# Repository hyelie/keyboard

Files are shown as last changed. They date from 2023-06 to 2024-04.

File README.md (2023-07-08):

# keyboard
repository for both-side-B reversed-tenkey hotswap split keyboard

## directory description
```
├─firmware
│  ├─hyelie - QMK firmware folder
│  └─kbfirmware - kbfirmware layout folder (for reference)
├─PCB
│  ├─gerber - my gerber file folder
│  └─lib - Kicad library folder
├─housing - 3D CAD folder for housing
├─specification - specifications
└─제작기 - manufacturing guide
```

## manufacturing guide

[키보드 제작기 1편. 왼쪽 PCB 설계](./%EC%A0%9C%EC%9E%91%EA%B8%B0/1.%20%EC%99%BC%EC%AA%BD%20pcb/README.md)

[키보드 제작기 2편. 양쪽 PCB 완성 및 주문](./%EC%A0%9C%EC%9E%91%EA%B8%B0/2.%20%EC%96%91%EC%AA%BD%20PCB%20%EC%99%84%EC%84%B1%20%EB%B0%8F%20%EC%A3%BC%EB%AC%B8/README.md)

[키보드 제작기 3편. 납땜 & 펌웨어 올리기](./제작기/3.%20납땜%20&%20펌웨어/README.md)

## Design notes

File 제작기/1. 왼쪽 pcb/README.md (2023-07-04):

최근들어 컴퓨터를 오래 하고 있으면 목이 자꾸 앞으로 빠지는 것 같아 스플릿 키보드를 하나 장만해야겠다고 생각했습니다. 

오쏘니 스태거니 하는 다양한 배열에 새로 적응하기 싫어 기존 배열로 찾아봤는데, 마음에 드는 배열이 없었습니다.

제일 마음에 안 드는 건 **오른쪽에 b키가 없다**는 거에요. 그래서 하나 만들기로 했습니다.

이 글은 스플릿 키보드를 제로베이스부터 만들면서 작성하는 글입니다. 저는 전공자도 아니고 회로 볼 줄도 모릅니다.
저는 맨땅에 머리 박으면서 했지만 이 글을 보는 **누군가에게 도움이 되기를** 바랍니다.
또 저도 뉴비인만큼 **고수분들께서 제 글을 보고 개선사항이나 잘못된 점을 지적**해주시면 좋겠네요.

## 목표
키보드를 만드는 방법은 크게 핸드와이어링/PCB 이렇게 2가지로 나뉘는데, 핸드와이어링의 경우 스위치나 하우징이 마음에 들지 않는 경우 처음부터 다시 만들어야 합니다.

스위치가 고장나는 일도 있을 것 같은데.. 이때마다 와이어링을 한다? 좀 아닌 것 같네요.

따라서 **핫스왑 소켓 + PCB**로 만드는 방법을 채용합니다.

 - 스플릿 키보드.
 - 양쪽에 모두 b키가 있어야 함.
 - 핫스왑 소켓. (스위치를 쉽게 교체할 수 있기 위함)
 - 텐키는 왼쪽 키보드의 왼쪽. (마우스 공간을 위함)
 - 사무실에서 사용할 수 있을 정도의 무소음, 또는 저소음
 - 오래 사용해도 손목이 아프지 않음

## 레이아웃
http://www.keyboard-layout-editor.com/
에서 키보드 레이아웃을 직접 만들어 볼 수 있습니다. 아래는 제가 목표로 하는 레이아웃입니다.

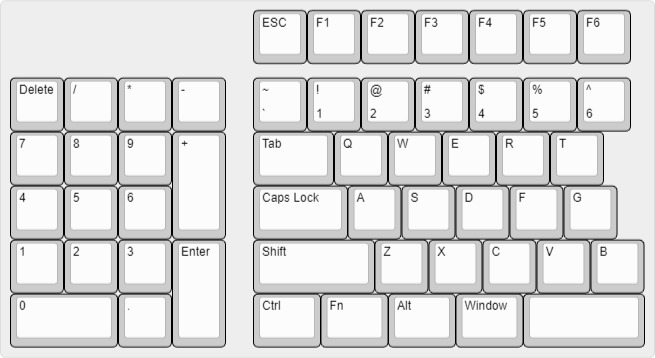
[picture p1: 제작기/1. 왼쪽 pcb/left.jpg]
left layout

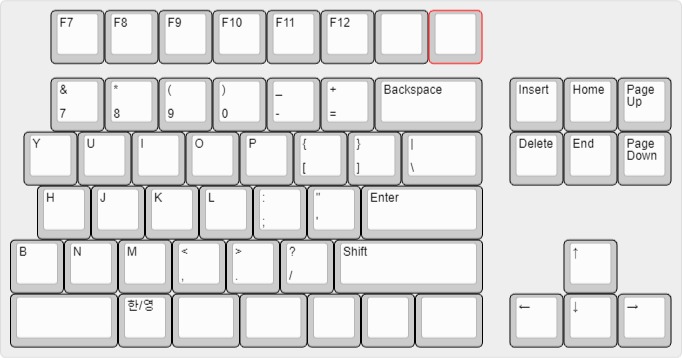
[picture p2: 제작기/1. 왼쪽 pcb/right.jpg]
right layout


기존 풀배열과 똑같습니다. F1~F12키는 자주 쓰진 않는데 없으면 서운하더군요.
텐키도 같은 맥락으로 숫자를 다라라락 입력하는 일이 많은데 텐키가 있으면 훨씬 편하니까요.
쓰잘데기없는 Number Lock이나 Print Sceen, Scroll Lock, Pause Break같은 키들을 다 지웠습니다.

참, 레이아웃을 만들 때 구입하고자 하는 **키캡을 먼저 알아보시는 것을 추천**합니다. 저의 경우는 무지성으로 레이아웃을 먼저 짰는데 오른쪽 스페이스바를 하나 더 주는 키캡이 거의 없더군요. 싼거 2개를 사던가, 여분을 매우 많이 주는 키캡을 사던가 2가지 방법 중에 하나를 택해야 할 것 같습니다. 여러분들은 키캡을 먼저 알아보시는 걸 추천드립니다...
* [키크론 체리프로파일 이중사출 PBT] 이 제품이 여분을 매우 많이 주더군요.

## 칩
칩은 국룰 칩인 ATmega32U4를 사용하려 했습니다. 그런데 칩 하나만 다는 게 아니라 파워, 축전지, 등등 신경 쓸 게 너무 많더군요.

그래서 **아두이노 프로 마이크로**를 사용하기로 했습니다. 이외에도 라즈베리 파이 피코나 Teensy 등 다양한 선택지가 있습니다.

회로에 자신있으신 분들은 직접 붙여도 될 것 같습니다. 공간활용이 훨씬 좋아지는 것 같아요.

## 좌우 연결 방법
크게 배선을 직접 잇는 방법, 케이블을 사용하는 방법 2가지로 나뉘는데, 배선을 직접 이으면 길이가 한정되어버리기 때문에 **케이블을 사용하는 방법**을 택하겠습니다.

케이블도 종류가 많은데, 많은 분들께서 TRRS 케이블을 사용해서 저도 TRRS를 택하려 했습니다...만

제가 만든 레이아웃은 풀배열인 만큼 개수가 많습니다. 좌우 모두 row가 6개, col이 11개입니다.

https://github.com/qmk/qmk_firmware/blob/master/docs/feature_split_keyboard.md

위 링크에 TRRS 케이블을 연결하는 방법이 있습니다. I2C 방식을 채용하면 되는데.. 이 방식은 핀을 2개나 먹을뿐더러 핀 사이에 뭔가 하나 더 납땜해 주어야 하네요.

여기서 문제가 하나 생깁니다. 아두이노 프로 마이크로에서 일반적으로 사용할 수 있는 핀의 개수는 18개입니다. 여기서 row 6개, col 11개를 하면 17개... 남는 핀이 없습니다.

추가로 뭔가 더 달기도 귀찮고, 아두이노 프로를 디솔해서 추가로 핀을 만들기도 두렵네요. 저는 키보드-키보드 연결 이외에 다른 연결은 하지 않을 것이니 **Serial Wiring 방식으로 TRS 연결**을 하겠습니다.

* VCC는 파워, GND는 접지, SCL은 정보가 왔다갔다하는 핀이라고 생각하시면 될 것 같습니다.

* TRS와 TRRS의 차이점은 구글링해보는 것을 추천합니다. TRS 소켓인 PJ-320이 kicad 심볼과 풋프린트를 찾기 쉽지 않아 TRRS 소켓인 PJ-320A를 사용했기 때문에, PJ-320A의 다리 4개가 어떤 역할을 하는지 정도는 알고 있으면 좋을 것 같습니다.

## 회로도
어떻게 만들지 대충 구상이 끝났습니다. 회로도를 작성할 차례입니다.

회로도는 크게 3단계로 나뉩니다.

0. 라이브러리 가져오기 + 각 심볼에 풋프린트 매핑하기
    * 제가 사용한 라이브러리는 아래에 링크로 두겠습니다.
1. 키 매트릭스 그리기
2. 키 매트릭스의 row/column과 아두이노 프로 마이크로 연결하기
3. 아두이노 프로 마이크로와 TRS 소켓 연결하기

추가로, 모두 배선을 해 버리면 굉장히 난잡해져 버리기 떄문에 [전역 라벨]이라는 기능을 활용하면 좋습니다. 같은 이름인 라벨을 같은 전선으로 이어져 있다고 취급해 줍니다.

이렇게 제가 삽질한 회로도입니다.

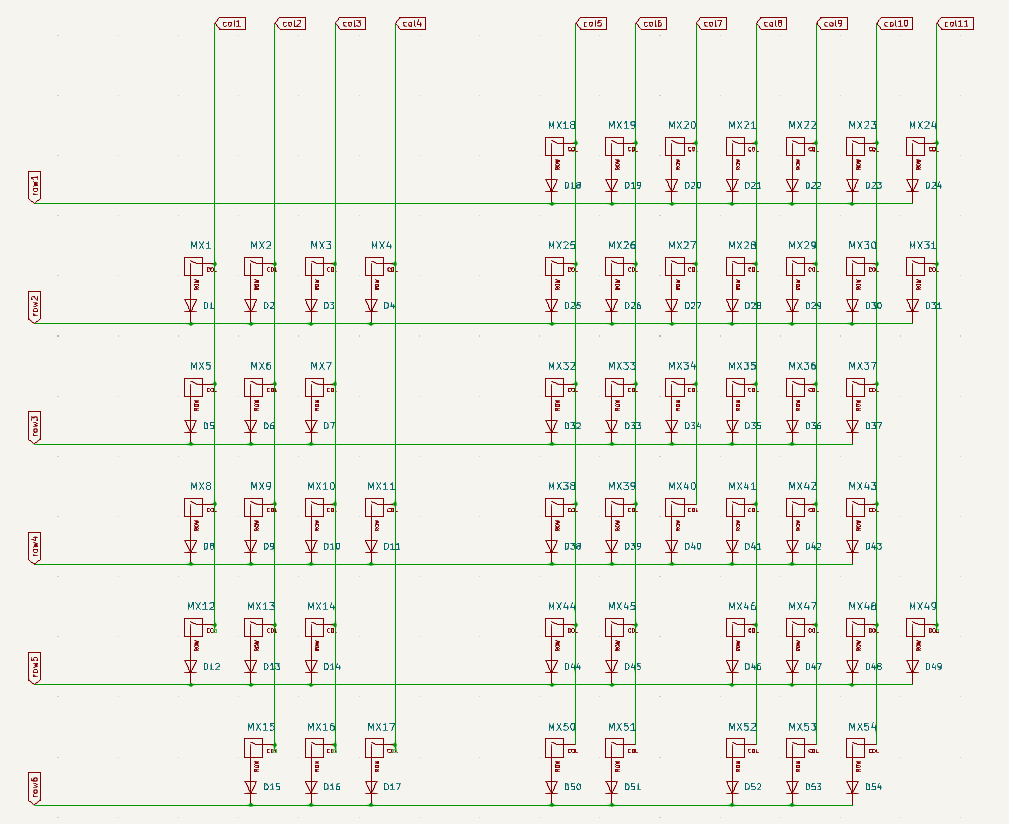
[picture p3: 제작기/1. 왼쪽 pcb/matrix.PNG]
circuit1

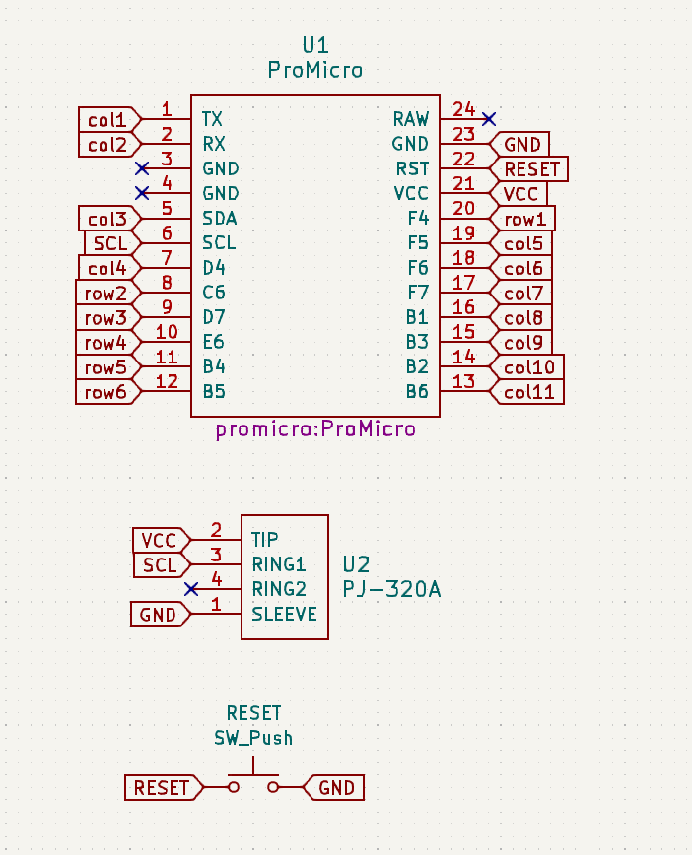
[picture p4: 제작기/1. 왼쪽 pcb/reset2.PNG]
circuit2


## PCB
회로도를 다 그렸다면, [도구 - 회로도로부터 PCB 업데이트]를 누르면 회로도에 있는 모든 심볼들에 대한 풋프린트를 로딩합니다. 만약 오류가 생겼다면... 해결하고, 풋프린트 로드를 어떻게든 해 봅시다.

PCB는 크게 2단계로 나뉩니다.

1. 로드했다면 생각했던 **레이아웃처럼 풋프린트를 배치**합니다.
2. 옅은 선으로 이어진 선(이 선들은 회로도에서 연결한 선이며, 가이드라인이라 보시면 됩니다.)를 연결합니다.

배선이 생각보다 많이 까다로웠습니다. 특히 한쪽 면으로만 배선하니까 너무 선들이 몰리는 경향이 있는 것 같아요. **양 면 모두 사용하는 것을 추천**드립니다.

추가로 [via]라는 것을 활용하면 좋습니다. 해 보시면 알겠지만 같은 면에 있는 배선은 교차할 수 없는데 **via를 사용해 선을 뒷면으로** 넘길 수 있습니다. 좀 더 공간을 활용할 수 있겟죠?

이렇게 제가 삽질한 PCB입니다.

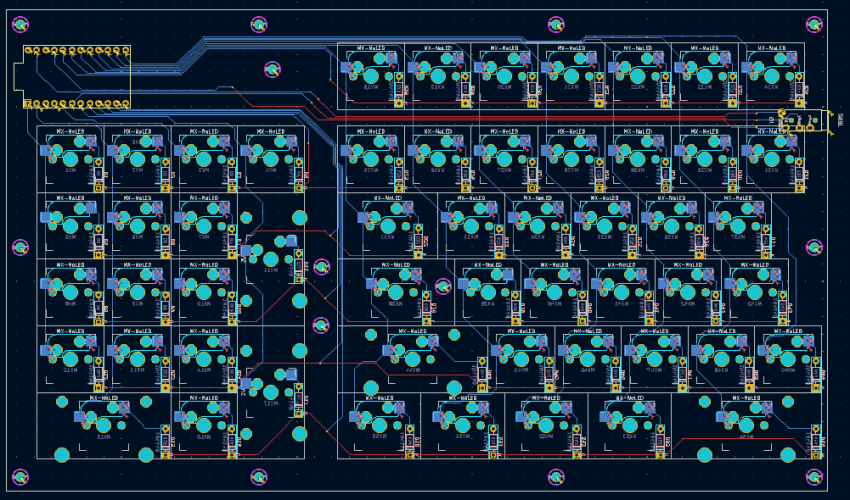
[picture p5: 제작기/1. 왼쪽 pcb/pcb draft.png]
pcb draft


* 이 때 PCB의 어느 위치에 나사를 체결할 건지도 중요하기 때문에 구멍 위치를 비워두셔야 합니다.

(추가) 리셋 버튼을 추가했습니다. 한 쪽은 아두이노 프로 마이크로의 RST와, 다른 한 쪽은 TRS의 GND와 이어줬습니다. (GND는 모두 한 선으로 이어져 있습니다.)

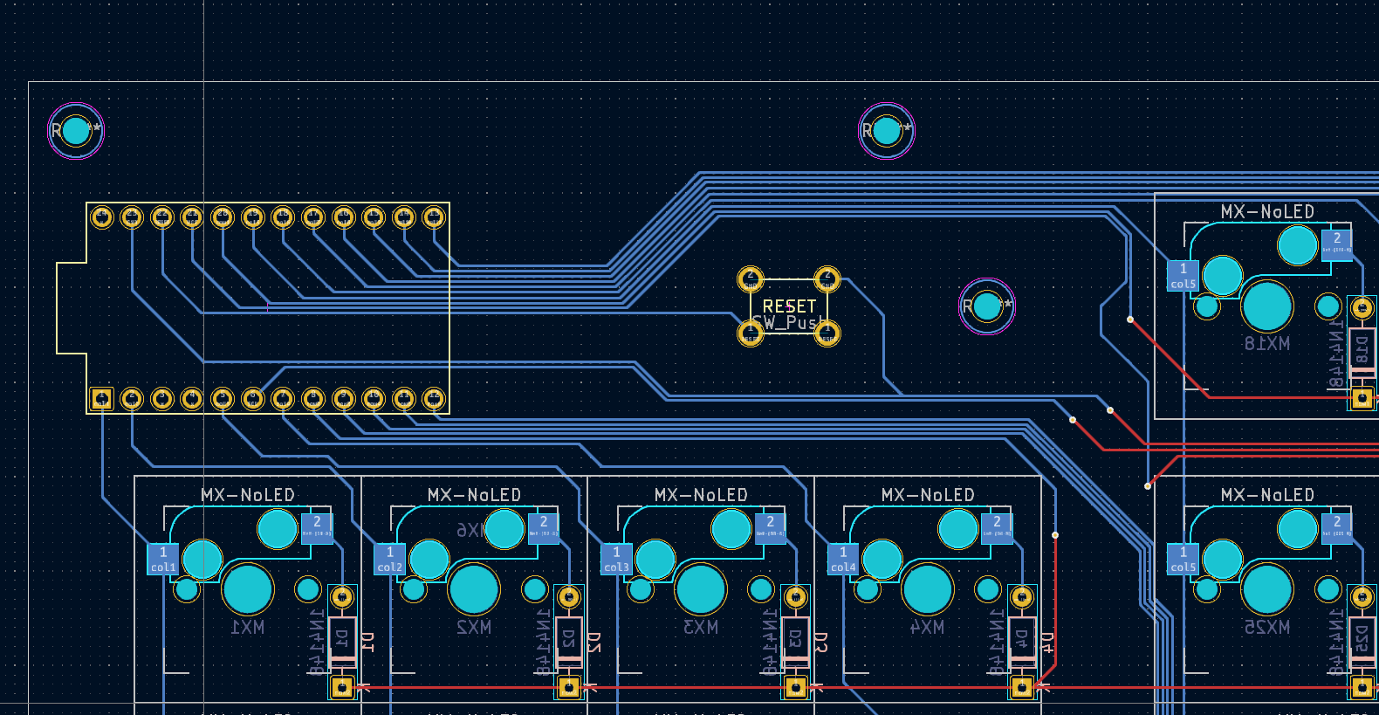
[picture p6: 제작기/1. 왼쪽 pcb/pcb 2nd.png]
pcb 2nd


## 다음...
풋프린트 검사를 돌렸을 때 별 이상이 없다면... 다음 단계로 넘어가도 될 것입니다.

다음에는 하우징과 견적내기(즐거운 쇼핑)을 하겠습니다.

## 마무리
고수분들 많은 훈수 부탁드립니다. 혹시나 풋프린트나 회로 파일 필요하시면 해당 레포지토리 안에서 찾을 수 있습니다.

## 참고
https://github.com/keebio/Keebio-Parts.pretty
 - TRRS 소켓인 PJ-320A를 가져다 썼습니다.

https://github.com/ai03-2725/MX_Alps_Hybrid
 - 키보드 스위치 심볼과 풋프린트를 가져다 썼습니다. vertical + hotswap 모두 있는 라이브러리입니다.
   
https://github.com/Biacco42/ProMicroKiCad
 - 아두이노 프로 마이크로 심볼과 풋프린트를 가져다 썼습니다.
 
https://github.com/qmk/qmk_firmware/blob/master/docs/feature_split_keyboard.md
 - TRS 연결 방법에 대해 나와있습니다.
   
https://www.clien.net/service/board/lecture/16615720
 - 키 매트릭스 만드는 방법을 참고했습니다. 설명이 잘 되어 있어요.
   
https://blog.naver.com/mine44
 - 질문 답해주셔서 감사합니다.

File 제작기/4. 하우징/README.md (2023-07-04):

녹색 선 : lock 걸린 것
검정 선 : lock 걸린 것에 dependency가 존재하는 것. 구속이 걸렸을 때 생긴다.
파란 선 : 아무것도 없이 자유롭게 움직일 수 있는 선

자주 쓰는 기능
모깎기 : 직각 선 2개를 연결하면 그 2개로 모깎기가 걸린다.
스케치 치수 : 특정 위치부터 얼마 떨어진 곳에 위치시킴. 구속이 걸린다. 단축키 D
돌출 : 해당 거리만큼 돌출시킴
offset : offset을 줄 수 있다.

parameter 관리 창 띄우는 방법 : 프로젝트 최상단 우클릭 - 타임라인 캡처 사용
수정 - 매개변수 관리

# 규격
상판 : 14 x 14 정사각형으로부터 offset 3mm, round 2mm로 깎으면 됨
스레드 인서트 규격 : M3 * Length * 외경

나사 규격
https://ko.aliexpress.com/item/1005002426046826.html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
머리 길이
M2 : 3.8mm
M2.5 : 4.5mm
M3 : 5.5mm

USB-C 규격
가로 9cm, 세로 2.56cm 정도?

스위치 규격
보강판 - 상판 끝까지 7-8mm
보강판 높이 1.5mm
보강판 - PCB 3.5mm
PCB 높이 1.6mm
PCB - 하판 3mm

아두이노 프로 마이크로 규격을 정확하게 모르니까.. 일단 집에 가서 width, height 재고 나서 그다음에 설계해야 할 듯? 안들어 갈 수도 있을 것 같음.

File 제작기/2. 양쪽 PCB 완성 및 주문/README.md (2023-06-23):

핫스왑 양쪽B 리버스텐키 스플릿키보드 제작기 2편입니다.

## 변경사항
### 목표 추가
제작하다보니 1편의 목표에서 몇 가지를 추가했습니다. 추가한 내용은 `사무실에서 사용할 수 있을 정도의 무소음, 또는 저소음`, 그리고 `오래 사용해도 손목이 아프지 않음`입니다.

### 레이아웃 변경
지난 제작기를 만든 이후, 왼쪽에 있는 텐키의 경우 숫자패드는 그대로 유지하되 `0`, `.`, `Enter`, `+` 등의 키들을 대칭이동하는 편이 좀 더 좋다`는 의견을 받았습니다. 실제로 가상 넘패드를 왼손으로 타이핑하려 하니 **엔터를 소지로, 자주 치는 0을 엄지로** 치는 게 훨씬 편했습니다. /, *, -까지는 굳이 대칭할 필요를 느끼지 못했고요.

또, 오른쪽 한영키의 우측에 있는 필요없는 키들이 아무리 봐도 이쁘지가 않아서 전부 다 삭제할까 했다가 한자키와 필요 시 사용할 매크로 키 2개만 냅뒀습니다. F12 오른쪽에 있던 빈 키 2개도 사용하지 않을 것 같아 삭제했고요.

변경사항 요약과 변경된 레이아웃은 아래와 같습니다.
 - 왼쪽 텐키의 `0`, `.`, `Enter`, `+`를 대칭이동
 - 오른쪽에서 사용하지 않는 키 삭제

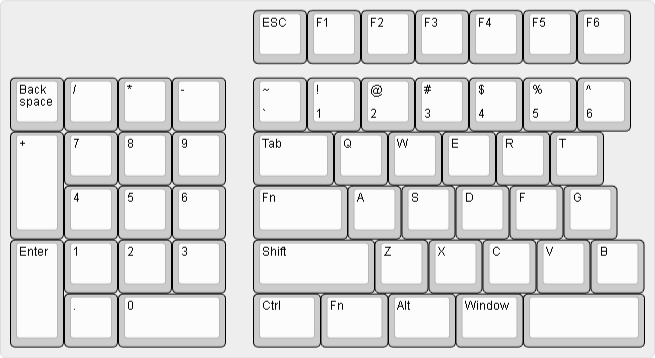
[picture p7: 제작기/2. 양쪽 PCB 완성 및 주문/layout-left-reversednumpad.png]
modified left layout

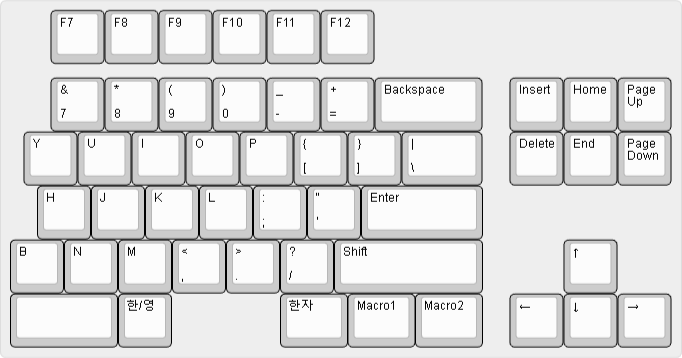
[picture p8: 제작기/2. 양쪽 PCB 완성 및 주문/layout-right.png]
modified right layout


## 변경된 사항을 반영한 회로도 & PCB
핫스왑 소켓을 사용하는 경우 스위치가 기판에 강하게 체결되지 않기 때문에 이를 보조해줄 보강판이 필수적입니다. 또한 어느 정도 있어 보이게 3D 프린터로 하우징을 만들 계획이기 때문에 PCB를 최대한 작고 컴팩트하게 만들려 했습니다. 보강판보다 작아야 하우징 내부에 들어가기도 하고, JLCPCB는 기판 크기로 가격을 산출한다는 이유도 있었습니다.

때문에 **PCB의 외곽선은 스위치 풋프린트에서 2.5mm 패딩**을 주었고, **라운드는 반지름 3mm 원**으로 깎았습니다. 나사구멍은 굳이 필요없지만 혹시 필요할 수도 있다고 생각해 M2 나사구멍을 모서리마다 하나씩, 그리고 비는 공간에 조금씩 넣어줬습니다. 나사구멍 위치를 맞추다 보니 모서리쪽 풋프린트는 예외적으로 조금 옮겨주었습니다.

#### 왼쪽
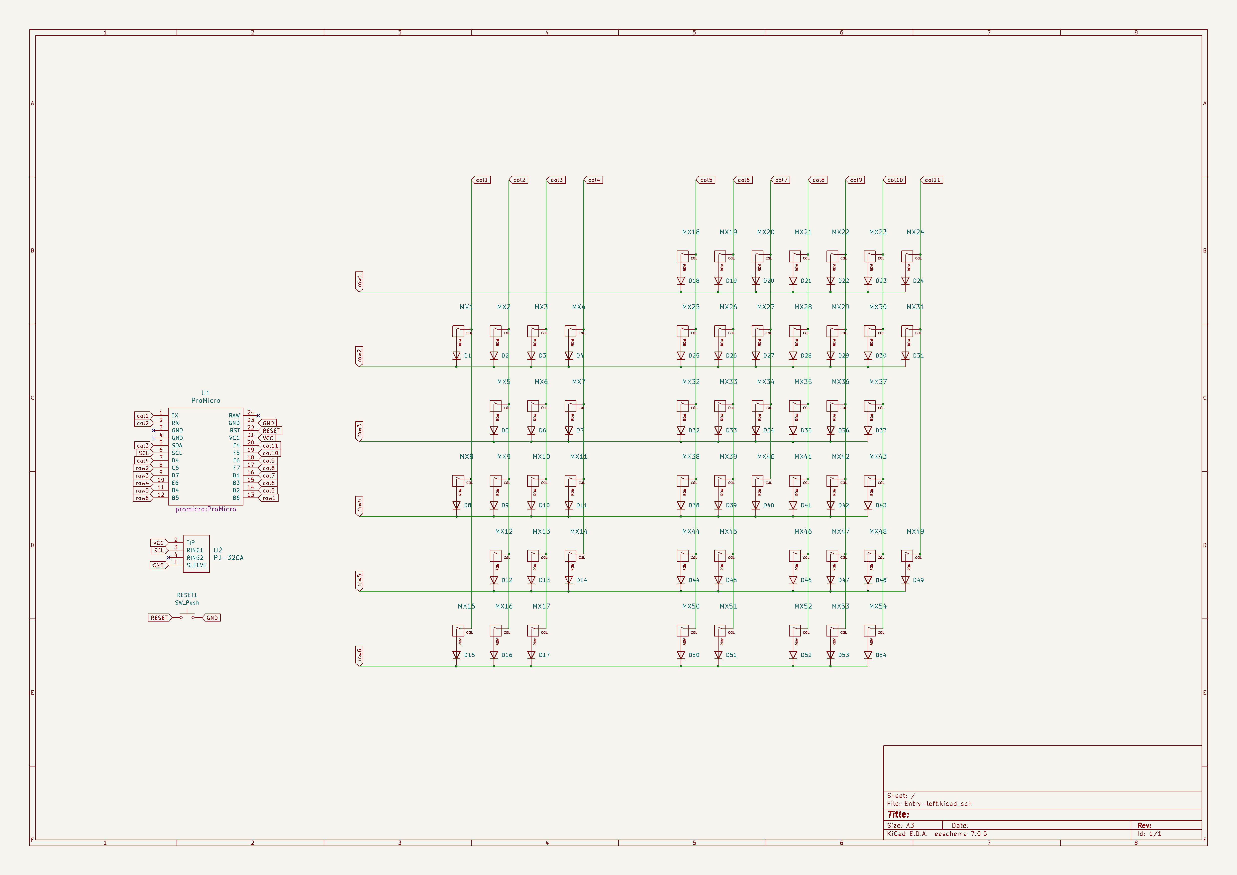
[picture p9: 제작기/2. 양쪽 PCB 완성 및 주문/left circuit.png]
left circuit

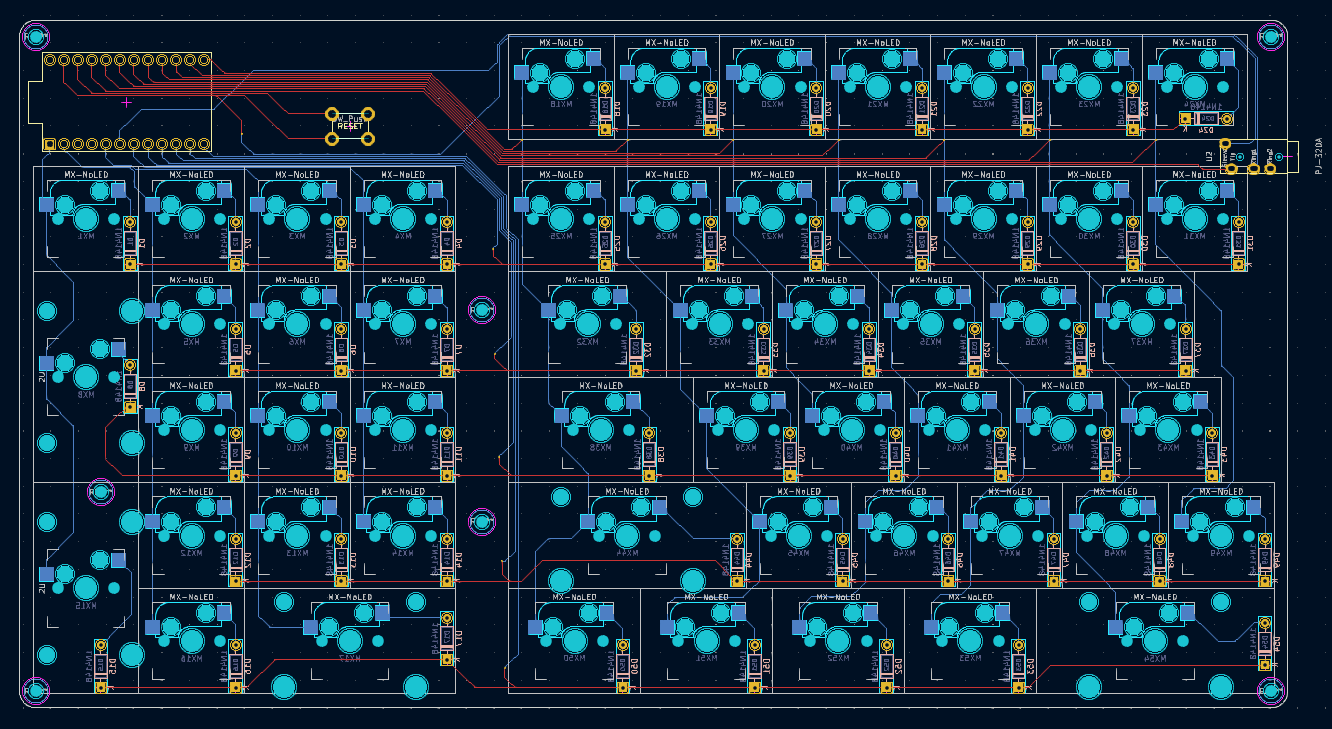
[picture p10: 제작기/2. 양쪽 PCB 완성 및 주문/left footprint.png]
left footprint


#### 오른쪽
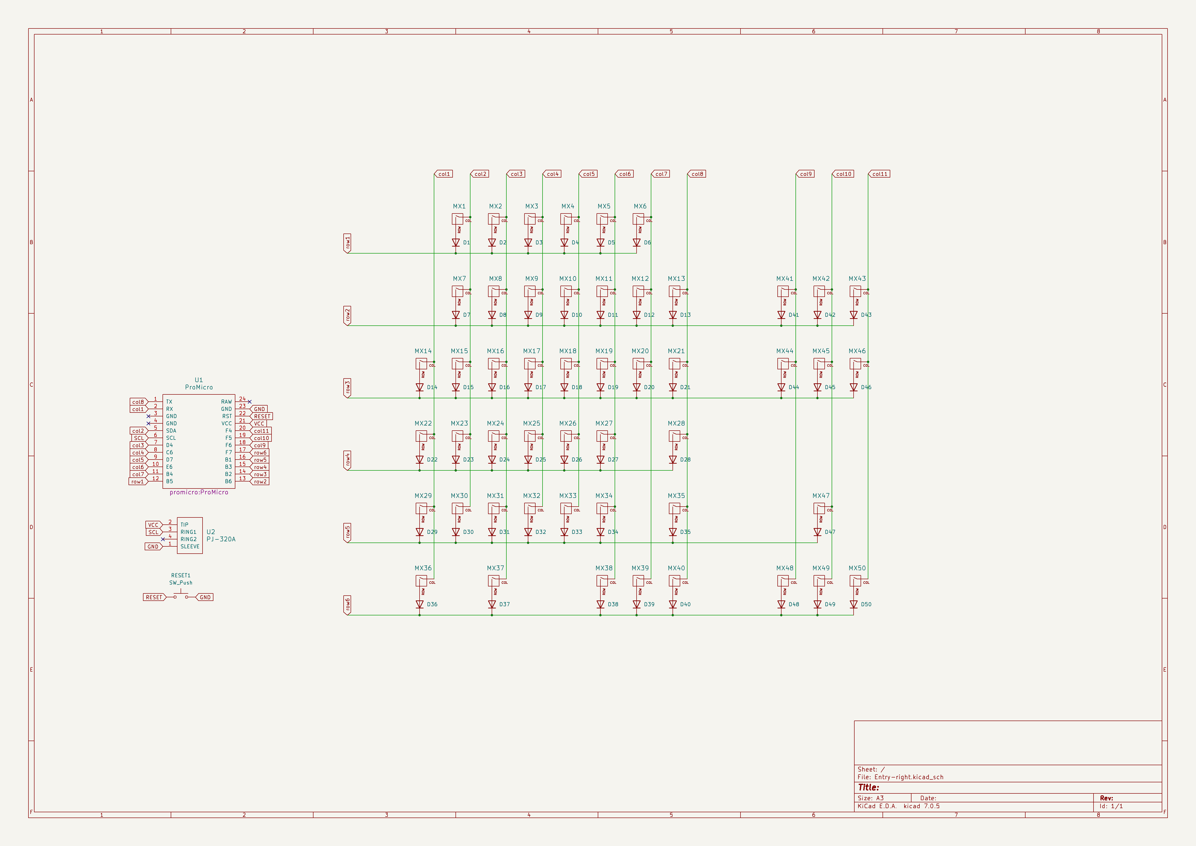
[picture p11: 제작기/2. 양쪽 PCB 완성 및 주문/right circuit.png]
right circuit

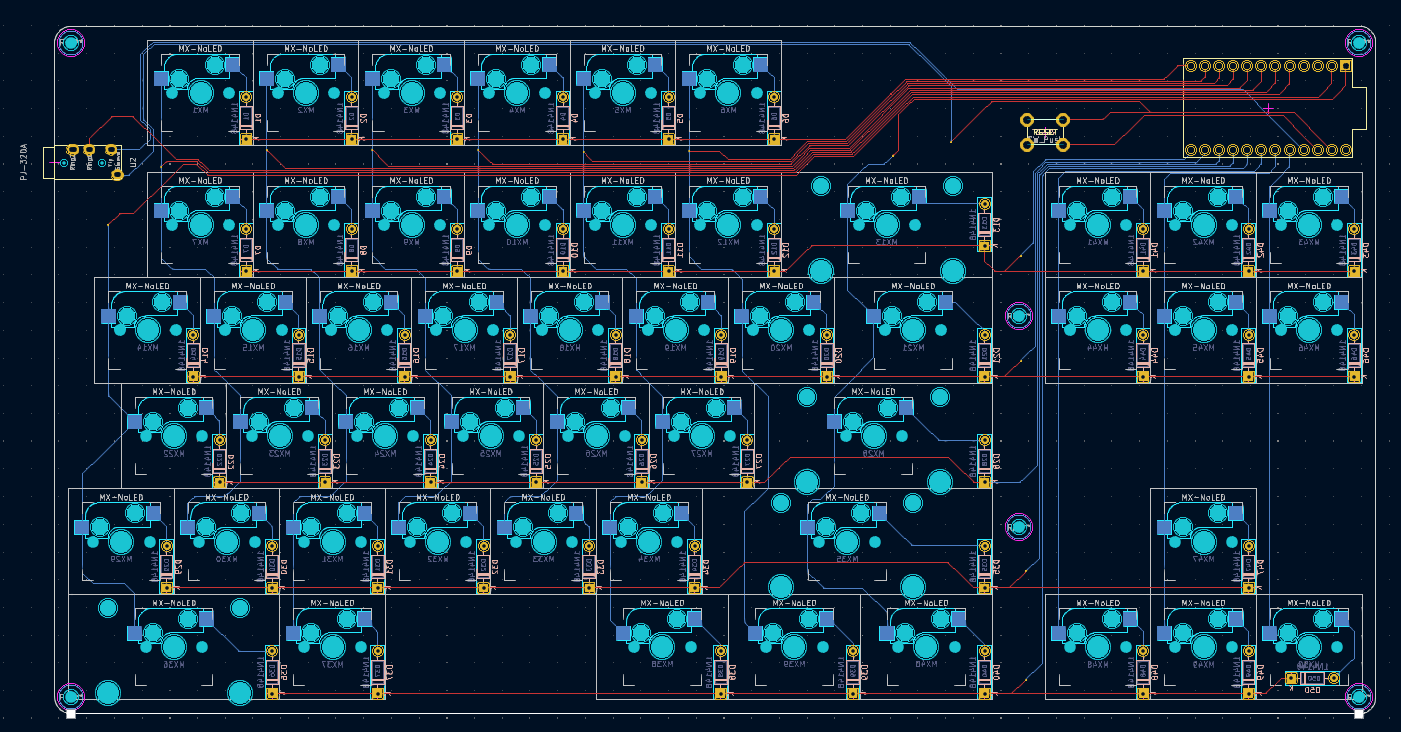
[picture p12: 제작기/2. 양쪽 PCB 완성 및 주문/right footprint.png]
right footprint


## 쇼핑
생각보다 살 게 많았습니다. 기계식은 처음이라 키캡, 스위치, 등 모든 걸 사야 했습니다. 

키캡의 경우 아래 2가지에 우선순위를 뒀습니다.
 - **각인**이 있어야 한다. 무각인 경우 숫자와 특수문자 입력할 때 힘드니까요.
 - **2U, 2.25U 여분이 하나씩** 있어야 한다. 단, 여기에는 다른 키의 **각인이 새겨진 것은 제외**한다. (스페이스바니까)

두 번째 조건을 만족하는 키캡이 없어서 키캡을 정말 오래 찾았습니다. 마음같아서는 그냥 저가형 대충 사고싶었는데 한 번 시작한 김에 마음에 딱 드는 걸 사자는 생각으로 비싼 것을 구매했습니다. PBT는 좀 오래간다는 이야기를 듣기도 했구요.

스위치는 아래 2가지에 우선순위를 뒀습니다.

 - **무소음/저소음**. 사무실에서 사용할 수 있을 정도의 소음을 기대하기 때문입니다.
 - **낮은 키압**. 키압이 높으면 오래 쓸 때 힘들 것 같더군요.
 
후보군을 추린 결과 오테뮤 라임, 또는 오테뮤 피치 2개가 최종 결승에 올랐고 피로감이 상대적으로 덜하다는 **오테뮤 피치**를 최종적으로 선택했습니다.

볼트와 스레드 인서트를 고를 때 많은 고민을 했습니다. 그런데 후보군들을 추리다보니 한 종류로 구매하는 거랑 세트로 사는거랑 가격이 크게 차이가 나지 않더군요? 아직 하우징이 완성되지 않은 시점이기 때문에 볼트 규격이 정해지지 않아 길이를 제가 선택할 수 있는 장점도 있고, 스레드 인서트 특성상 한 번 박아넣으면 빼기 어렵기 때문에 여분이 많이 필요할 거라 생각했어요.

그래서 **[M2 + M2.5 + M3] 세트**를 구매했습니다. PCB에 M3 구멍은 크다고 생각해 PCB는 M2 구멍을 뚫어놔서 만약 PCB를 볼트로 체결할 일이 있다면 M2로 체결하고, 하우징은 M3로 체결하면 될 것 같네요.

## 결산
결산입니다. 많은 후보군을 고르고 가격과 배송일자를 비교해가며 추리고 추려서 구매했지만 생각보다 금액이 꽤 나왔습니다. 

특히 많은 커스터마이징들이 PCB를 최대한 작게 + 대칭형으로 우겨넣는 이유를 알게 되었습니다. 크게 만들 경우 이게 가격이 꽤 나갑니다.

모든 가격은 택배비 포함입니다.

|분류|가격|링크|
|-----|-----|-----|
|좌우 PCB 제작 비용 (JLCPCB)|48,225원|https://jlcpcb.com/|
|아두이노 프로 마이크로 2개|12,406원|https://ko.aliexpress.com/item/1005001622051348.html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|
|1N4148 다이오드 120개|1,920원|https://www.devicemart.co.kr/goods/view?no=25|
|ITS-1105-5mm 리셋 버튼 10개|440원|https://www.devicemart.co.kr/goods/view?no=34555|
|PJ-320A TRS 커넥터 5개|880원|https://www.devicemart.co.kr/goods/view?no=15049504|
|devicemart 택배비|3,000원|1N4148 다이오드, ITS-1105-5mm 리셋 버튼, PJ-320A TRS 커넥터|
|TRRS 케이블|4,028원|https://ko.aliexpress.com/item/1005003973270372.html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|
|카일 핫스왑 소켓 150개|15,144원|https://ko.aliexpress.com/item/32951252318.html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|
|보강판용 스태빌라이저 2세트|12,813원|https://ko.aliexpress.com/item/1005004318868472.html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|
|M2, M3 나사 500pcs 세트|4,311원|https://ko.aliexpress.com/item/1005002426046826.html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|
|M2, M2.5, M3 스레드 인서트 500pcs 세트|8,835원|https://ko.aliexpress.com/item/1005005231413136.html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|
|키크론 키캡 219키|44,800원|https://brand.naver.com/keychron/products/7674815629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|
|오테뮤 라임 V2 스위치 (5핀) 120개|31,800원|https://smartstore.naver.com/happysaturday/products/8431789340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|
|오테뮤 피치 V2 스위치 (5핀) 110개|27,800원|https://smartstore.naver.com/happysaturday/products/8362296391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|
|인두기, 납, 등등|0원 (메이커스페이스 이용)|https://www.scube.or.kr/?page_code=otherpage&code=map|
|3D 프린터 및 필라멘트|0원 (메이커스페이스 이용)|https://www.scube.or.kr/?page_code=otherpage&code=map|

여기까지 **184,602원**, 오테뮤 라임까지 216,402원입니다.

오테뮤 라임은.. 피치인 줄 알고 잘못 구매했습니다. 능지이슈 ㅠㅠ 기왕 잘못 산 김에 라임도 한 번 테스트해보고, 마음에 들면 라임으로 스위치 교체를 해 볼 생각입니다. 핫스왑이니까요! 마음에 안 들면 당근에 팔아버리죠 뭐.

기타
|분류|가격|링크|
|-----|-----|-----|
|정밀 핀셋|2,391원|https://ko.aliexpress.com/item/32845524877.html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|
|PE PCB 스위치 스티커|3,890원|https://ko.aliexpress.com/item/1005004626661572.html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|
|가스켓 스펀지|4,831원|https://ko.aliexpress.com/item/1005004266820408.html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|
|풀배열 키보드 흡음재|8,900원|https://smartstore.naver.com/do9/products/4807602807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|
|800x300x2mm 주문제작 장패드|8,316원|https://www.aliexpress.com/item/1005005060366601.html?spm=a2g0o.order_list.order_list_main.5.2262140fJsfQFT|

여기까지 28,328원입니다.

굳이 필요없는? 것들이긴 했는데 한 번 사니까 계속 이것저것 알림이 와서 ㅋㅋㅋ 사고 싶은 마음에 사버렸습니다. 안 쓸 수도 있지만요... 흡음재들의 경우에는 타건이 시끄러울 경우 가스켓 마운트로 하우징을 교체할 생각에 구매했습니다.

총지출 : 244,730원, 오테뮤 라임을 제하면 **212,930원**입니다. 하나사나 사다보니까 어느 순간 돌이킬 수 없는 강을 건넜더군요...

다음은 하우징 설계 / 제작으로 돌아오겠습니다. 일단 간단한 구조로 하우징을 만들어 보고, 시간이 난다면 가스켓 마운트로도 설계해 보겠습니다.

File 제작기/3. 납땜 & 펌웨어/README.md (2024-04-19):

지난 글에서 하우징 설계 / 제작으로 돌아오겠다고 예고했는데, CAD로 만들아가 주문한 아두이노 프로 마이크로가 PCB 바깥으로 조금 더 나갈 것 같다는 직감이 매우 강하게 들어 판매자에게 "너네 규격 어떻게 됨?" 이라고 물었더니 "나도 모름 ㅇㅇ 니가 확인하셈"이라는 답변이 와서 하우징 제작을 일단 미뤘습니다. 주문한 스레드 인서트와 볼트도 오지 않았구요. 

그래서 **납땜&펌웨어**를 먼저 올리기로 했습니다.

## 납땜
집 근처에 있는 메이커스페이스에서 인두기 + 납까지 빌려 납땜했습니다. 초등학교 때 납땜한 이후로 거의 10년?만에 다시 잡았는데, 하다 보니 적응되더군요.

납땜할 때는 몇 가지만 잘 지키면 큰 이상 없이 끝낼 수 있습니다.

1. **인두기 먼저 대고 - 납을 대고 납을 녹힌 후 - 납을 떼고 - 인두기를 뗀다.**
2. 납이 적은 경우는 추가할 수 있지만 **납이 많은 경우는 복구하기가 상당히 힘들다.**
3. 하나의 구멍을 납땜하면 부품이 거의 고정되기에 **하나 납땜한 후 틈이 없는지 잘 확인**해야 한다. 이미 납땜을 완료한 상태에서 수정하기는 상당히 힘들다.

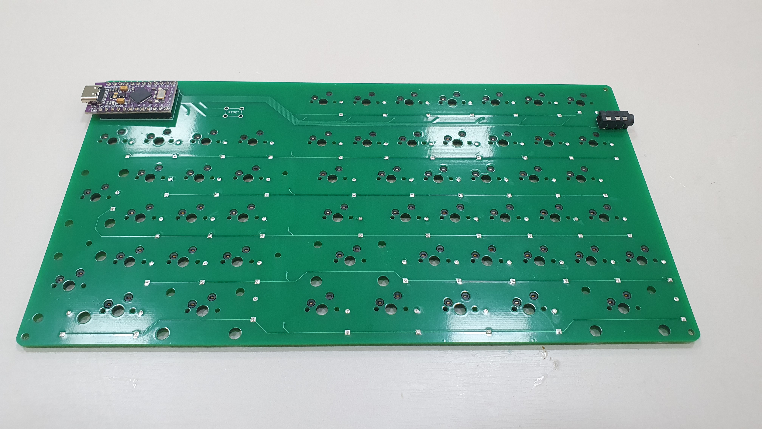
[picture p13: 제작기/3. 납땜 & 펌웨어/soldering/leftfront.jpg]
앞면

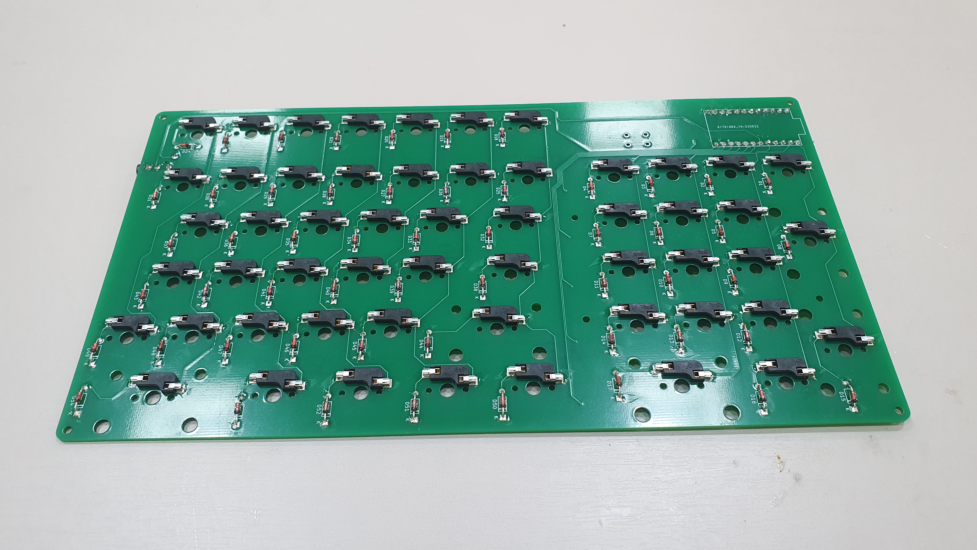
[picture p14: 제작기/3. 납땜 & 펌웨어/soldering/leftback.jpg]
뒷면


어찌어찌 잘 끝냈습니다. 그런데 다 하고 집에 와보니...

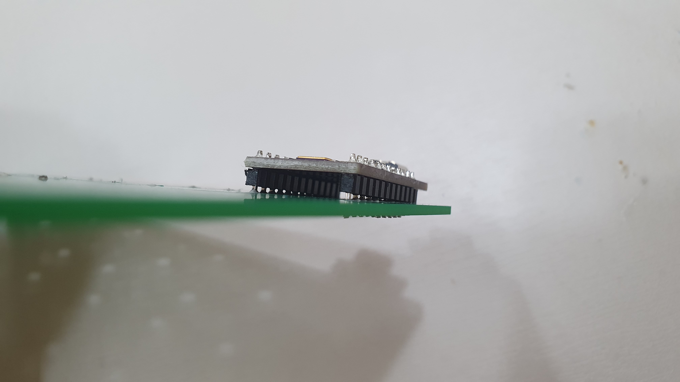
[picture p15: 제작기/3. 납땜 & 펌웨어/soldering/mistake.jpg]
실수


프로 마이크로를 납땜한 부분 한쪽이 살짝 들린 채로 납땜을 했더군요. 수정하려면 총 24개의 핀을 디솔더링해야 하는데... 디솔더링 도구가 없기도 하고 그렇게 큰 영향을 주지도 않을 것 같아서 그냥 이대로 진행하기로 했습니다. 

## 펌웨어
다음 과정을 통해 키보드 레이아웃을 변경하고 아두이노 프로 마이크로에 펌웨어를 올렸습니다.

편의상 왼쪽 부분을 `LEFT`, 오른쪽 부분을 `RIGHT`라고 대문자를 사용해 지칭하겠습니다.

여기서는 **`LEFT`를 master**로 만드는 것을 가정하고 진행하기 때문에 키 입력 등의 **모든 정보는 `LEFT`**에 올라가며, 펌웨어 또한 `LEFT`에만 올라갑니다.

* 새로 만드는 등의 이유로 키보드 레이아웃을 변경할 때는 모든 과정을 거쳐야 합니다. 키 매핑만 변경하고 싶을 경우 6번 이후의 과정만 진행하면 됩니다.

1. [QMK MSYS](https://msys.qmk.fm/)와 [QMK Toolbox](https://github.com/qmk/qmk_toolbox)를 다운로드 받습니다. **QMK MSYS**는 작성한 파일을 아두이노 프로 아두이노에 올리기 위한 **.hex 파일로 컴파일**하며, **QMK Toolbox**는 .hex파일을 **아두이노 프로 아두이노에 올리는 기능**을 합니다.

2. [keyboard-layout-editor](http://www.keyboard-layout-editor.com/)에서 작성한 `LEFT`의 레이아웃을 [kbfirmware](kbfirmware.com)에서 올립니다. WIRING, PINS, KEYMAP을 수정한 후 SETTINGS에서 `Save Configuration`을 클릭해 layout.json을 다운로드 받습니다.
    - WIRING은 각 스위치가 어떤 행/열의 교차점에 위치하는지, PINS는 행/열이 어떤 핀맵에 위치하는지, KEYMAP은 사용할 키 매핑을 의미합니다.
    - PIN은 [golem Pro Micro pinout](https://golem.hu/article/pro-micro-pinout/)에서 확인할 수 있습니다.

3. layout.json 파일을 [noroadsleft.github.io/kbf_qmk_converter/](noroadsleft.github.io/kbf_qmk_converter/)에 넣고 다운로드 받습니다. 폴더를 해제하면 info.json, rules.mk, keymaps/default/keymap.c 3개 파일이 있습니다.

4. rules.mk에 `SPLIT_KEYBOARD = yes`를 추가합니다. 스플릿 키보드로 쓰겠다는 뜻입니다.

5. config.h 파일을 새로 만들고 아래 코드를 작성합니다. **USB가 꽂힌 곳을 master**로 보겠다는 것입니다.
    ```
    #ifndef CONFIG_H
    #define CONFIG_H

    #define MASTER_LEFT
    #define SPLIT_USE_DETECT

    #endif
    ```

6. LEFT가 RIGHT의 RIGHT의 입력 정보를 받아오기 위해 info.json에 다음 코드를 추가합니다. 여기서 `soft_serial_pin`은 연결한 선에 해당하는 핀 번호를, `matrix_pin`은 오른쪽 절반의 키 매트릭스에 해당하는 핀 매핑을 적습니다.
    - `soft_serial_pin`은 `SCL`에 연결했기 때문에 `D0`로, matrix_pins는 `RIGHT`의 핀을 작성합니다.
    ```
    "split": {
            "soft_serial_pin": "D0",
            "matrix_pins": {
                "right": {
                    "rows": ["B5", "B6", "B2", "B3", "B1", "F7"],
                    "cols": ["D2", "D1", "D4", "C6", "D7", "E6", "B4", "D3", "F6", "F5", "F4"]
                }
            }
        },
    ```

7. [QMK 공식 스플릿 키보드 문서](https://github.com/qmk/qmk_firmware/blob/master/docs/feature_split_keyboard.md#layout-macro)를 참고해 info.json과 keymap.c를 수정합니다.
    - 지금까지 LEFT를 작업했기 때문에 **RIGHT에 해당하는 부분이 비어있는 상태**입니다. `RIGHT`에 해당하는 부분도 1번, 2번 과정을 진행해 info.json, rules.mk, keymaps/default/keymap.c 3개 파일을 다운로드 받고 안에 있는 내용을 복사+붙여넣기합니다.
    - keymap.c 파일은 레이아웃과 동일하게, **원래 것의 오른쪽에 추가**합니다.
    - 공식 문서에 적혀있듯 QMK의 키 매트릭스는 row를 2배로 인식합니다. 따라서 info.json에 원래 있던 `LEFT`에 해당하는 layout은 그대로 두고, **`RIGHT`에 해당하는 layout의 모든 matrix의 처음 값에 왼쪽 layout row size를 더합니다.**
    ```
    {"label": "K11 (B6,D1)", "matrix": [1, 1], "x": 0.75, "y": 1.25},
    ->
    {"label": "K11 (B6,D1)", "matrix": [7, 1], "x": 0.75, "y": 1.25}
    // LEFT의 행 크기가 6이므로 6을 더한 모습입니다.
    ```

    - 제가 작성한 예시는 다음 링크에서 확인할 수 있습니다. [keymap.c 링크](../../firmware/hyelie/keymaps/default/keymap.c), [info.json 링크](../../firmware/hyelie/info.json)

    - 추가로, 개발자로 일하게 되면서 맥을 사용하게 되었습니다. 맥에서만 사용하는 키보드, 윈도우에서만 사용하는 키보드 2개를 분리해서 사용하다가 OS 감지 기능에 대해 알게 되어 적용했습니다.

8. `C:\User\qmk_firmware\keyboard` 안에 펌웨어 폴더를 복사해 넣은 상태에서 다음 명령어를 실행해 컴파일합니다. 폴더는 다음 링크에 있습니다. [링크](../../firmware/hyelie/)
    - 컴파일한 결과로 나오는 .hex 파일은 `C:\User\qmk_firmware\.build`에 저장됩니다. 
    ```
    qmk compile -kb entry/hyelie -km default
    ```

9.  QMK Toolbox를 실행하고 앞 단계에서 컴파일한 .hex 파일을 로드합니다. 이후 아두이노를 컴퓨터에 연결하고 리셋 버튼을 눌러 아두이노를 인식한 컴퓨터에 flash 버튼으로 .hex 파일을 아두이노 프로 마이크로에 올립니다. **_flash 중간에 절대 선을 빼지 마세요!_**
   - 리셋 버튼이 없다면 전선을 쓰든 뭘 쓰든 해서 아두이노 프로 마이크로의 `RST`와 `GND`를 잠시 연결해 주면 됩니다.
   - 리셋 버튼을 누르면 아래와 같은 내용이 QMK Toolbox에 나옵니다. 이 상태에서 Flash를 클릭하면 로그가 나온 후 펌웨어를 올린 후 연결을 해제한다는 메시지가 나옵니다.
```
Caterina device connected (usbser): Microsoft USB 직렬 장치(COM5) (2341:0037:0001) [COM5]
... (flash 로그)
Flash complete
Caterina device disconnected (usbser): Microsoft USB 직렬 장치(COM5) (2341:0037:0001) [COM5]
```

10.  [keyboardtester.com](https://www.keyboardtester.com/)에서 키 매핑이 잘 되었는지 테스트합니다.

## 정리...
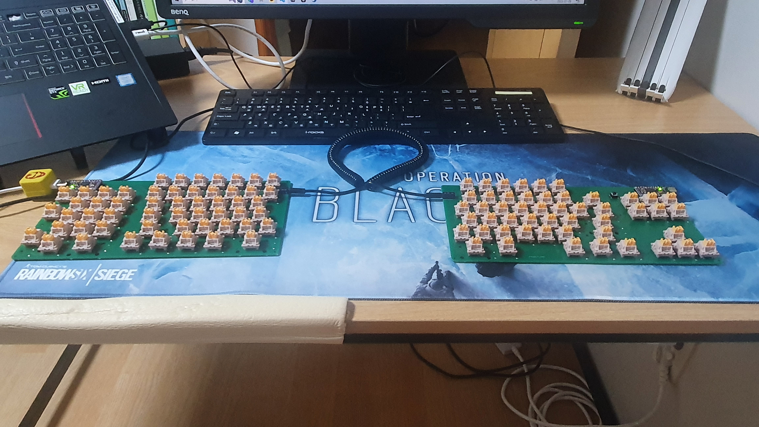
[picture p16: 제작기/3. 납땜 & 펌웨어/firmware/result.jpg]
결과물


많은 우여곡절을 거쳐 여기까지 왔습니다. 모든 키 잘 되구요, 추가적으로 매핑했던 레이어 기능인 caps lock + wasd로 방향키 지정하는 기능도 잘 됩니다.

> caps lock은 기능을 삭제했고, wasd는 조금 불편해서 esdf로 키를 옮겼습니다. 항상 f에 검지가 올라가 있으니까요.
> 원래 방향키를 오른쪽으로 입력하다 보니 왼쪽 esdf로 입력하는 것이 불편했습니다. esdf와 같은 이유로 caps lock + ijkl에 방향키를 할당했고, fn + jl에 end/home을 할당했습니다.

다음에는 진짜 하우징 제작기로 돌아오겠습니다.

관심 가져주신 모든 분들, 도움 주신 모든 분들 감사합니다. 혹시나 도움이 필요하신 분들은 연락 주시면, 도움 드릴 수 있는 선에서는 최대한 도움 드리겠습니다.

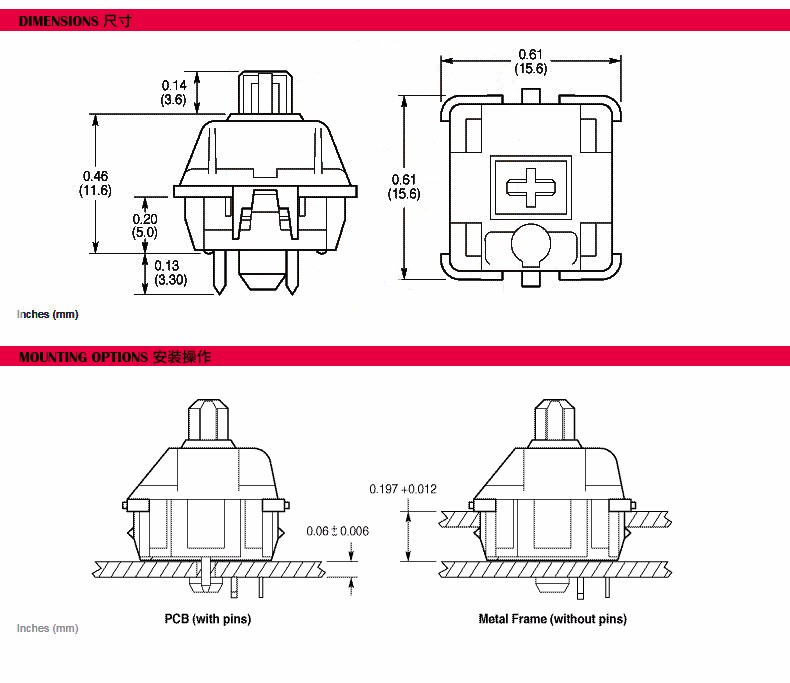
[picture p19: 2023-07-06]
specification/switch.jpg

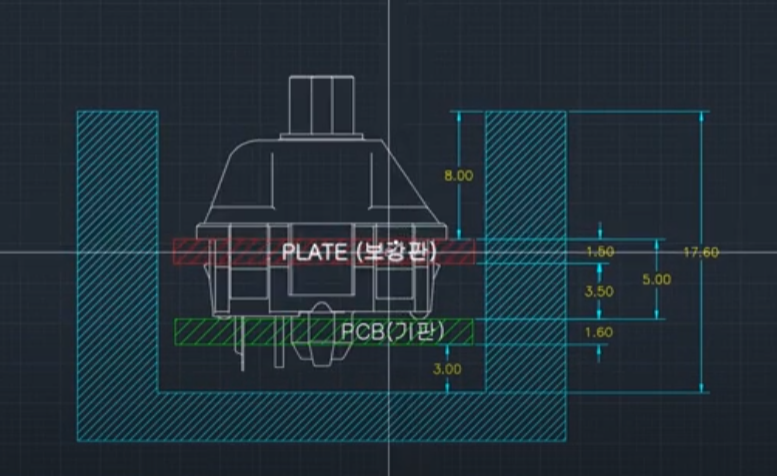
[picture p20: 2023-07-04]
specification/switch specification.PNG

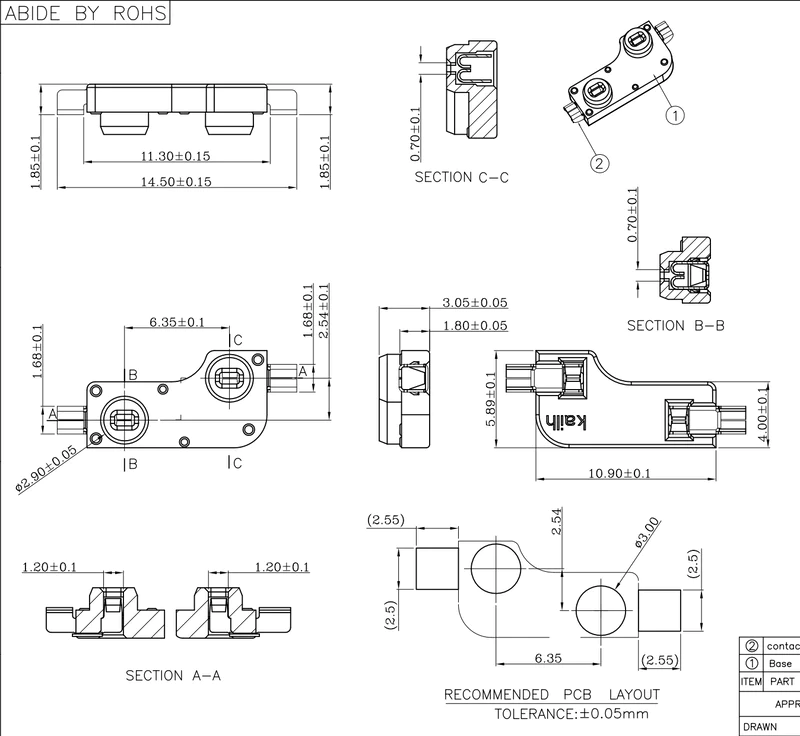
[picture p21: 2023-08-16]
specification/hotswap socket.webp

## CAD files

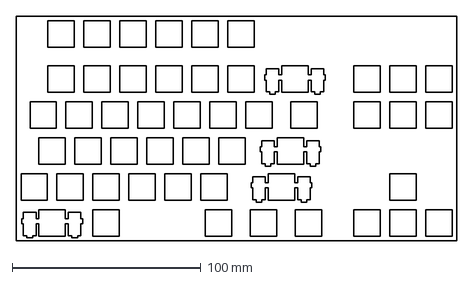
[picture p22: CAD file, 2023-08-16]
housing/keyboardcad/right layout.dxf
233.3 x 119.0 mm

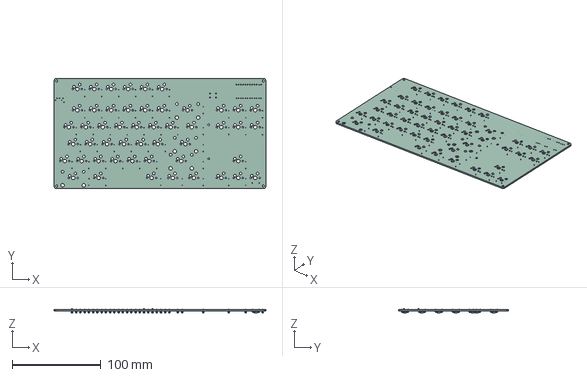
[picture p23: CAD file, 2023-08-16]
housing/pcb step files/Entry-right.step
238.4 x 124.1 x 5.01 mm
Entry-right PCB

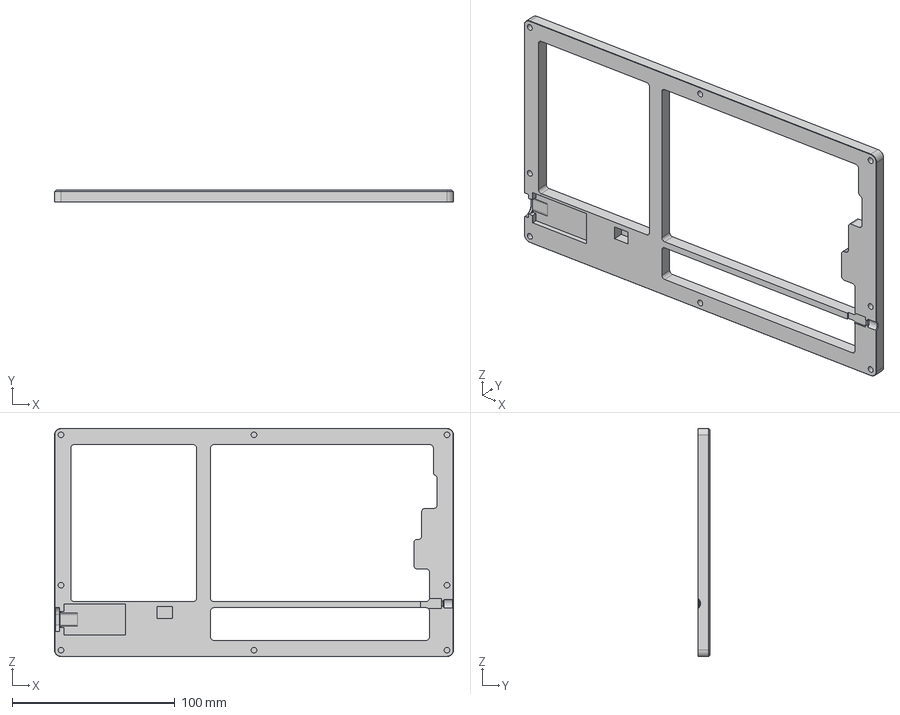
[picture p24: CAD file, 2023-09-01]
housing/result/left top plate.step
244.8 x 7.50 x 140.0 mm

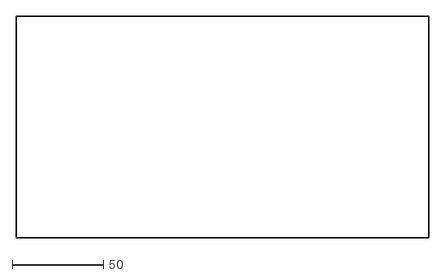
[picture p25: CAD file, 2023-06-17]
housing/swillkb/swillkb-bottom.dxf
225.8 x 121.1

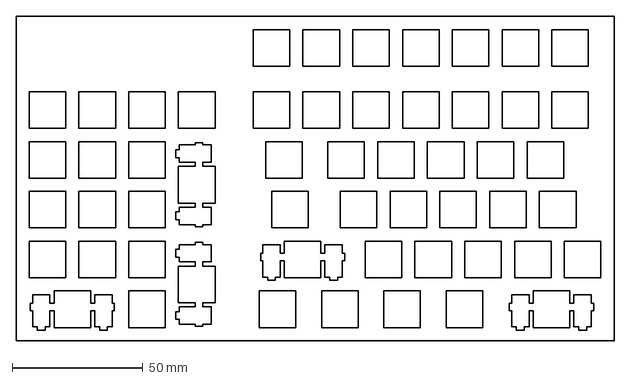
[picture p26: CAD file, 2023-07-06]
housing/keyboardcad/keyboardcad.dxf
228.8 x 124.0 mm

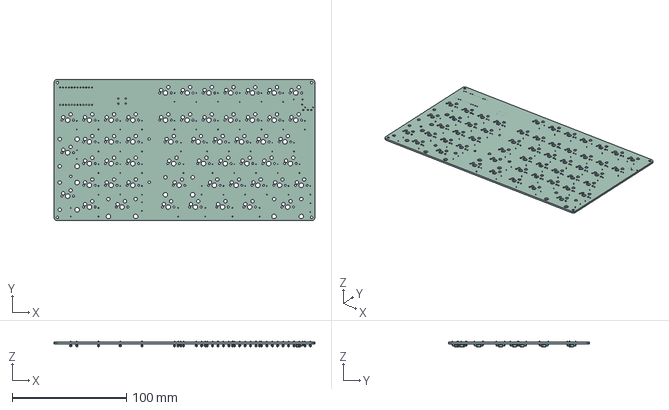
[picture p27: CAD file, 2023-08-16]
housing/pcb step files/Entry-left.step
228.8 x 124.1 x 5.01 mm
Entry-left PCB

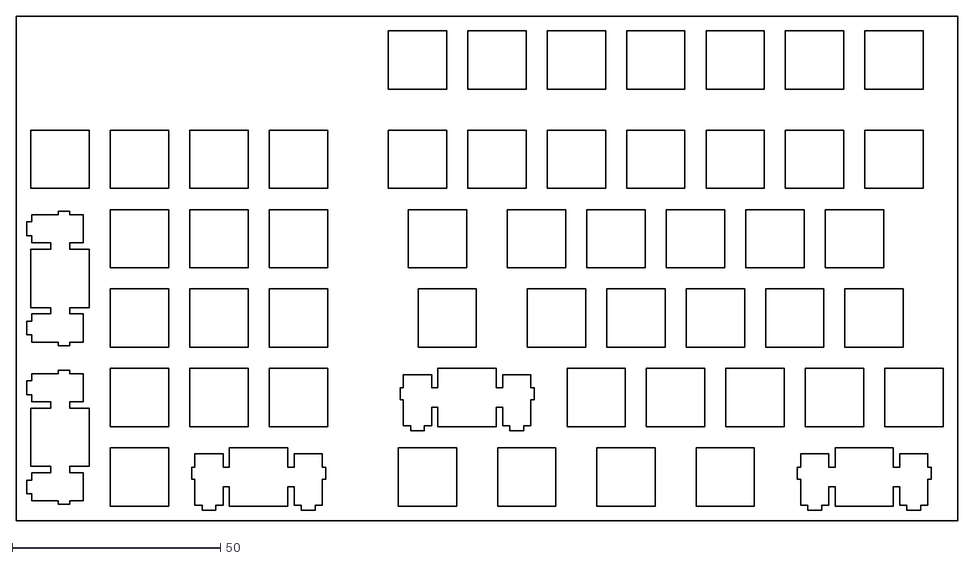
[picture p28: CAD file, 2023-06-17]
housing/swillkb/swillkb-switch.dxf
225.8 x 121.1

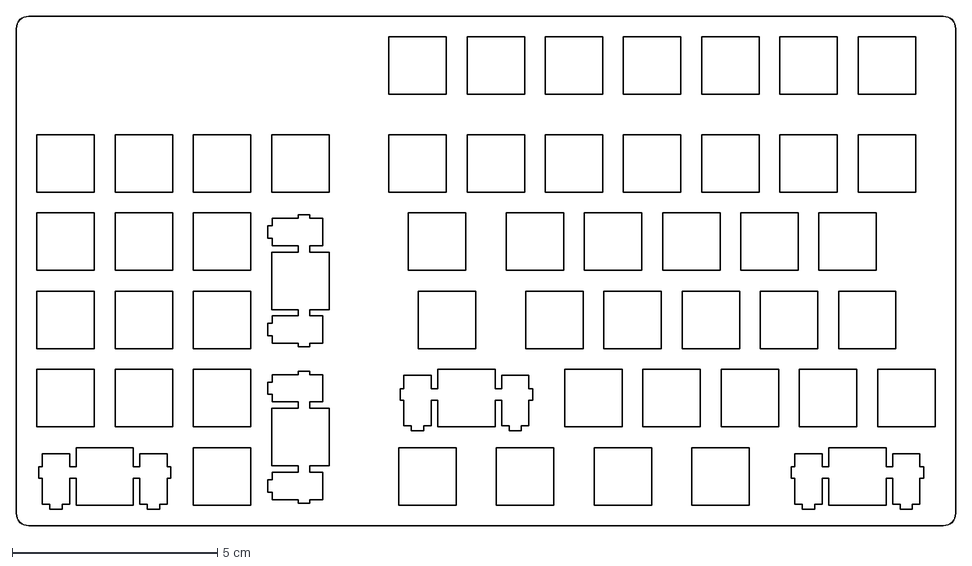
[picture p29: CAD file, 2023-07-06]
housing/keyboardcad/left PCB v1.dxf
22.9 x 12.4 cm

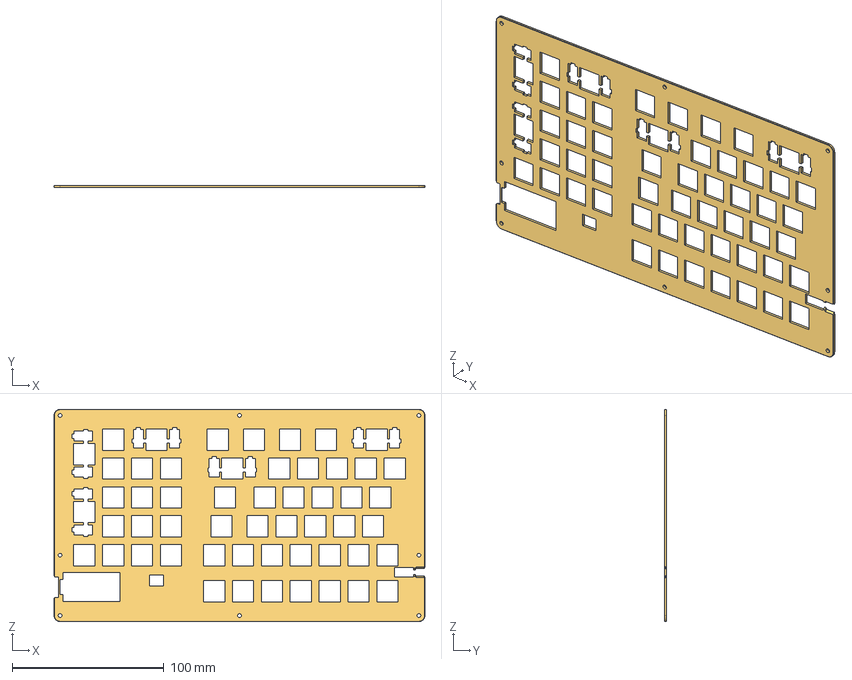
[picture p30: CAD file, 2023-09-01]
housing/result/left plate.step
244.8 x 1.50 x 140.0 mm

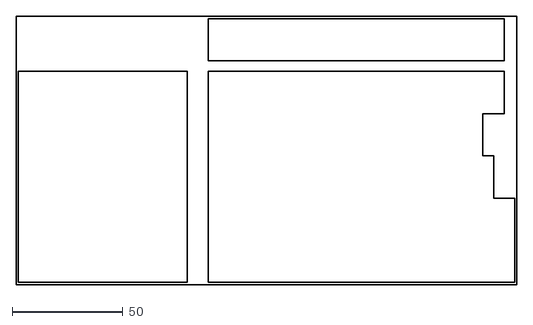
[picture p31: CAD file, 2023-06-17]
housing/swillkb/swillkb-top.dxf
225.8 x 121.1

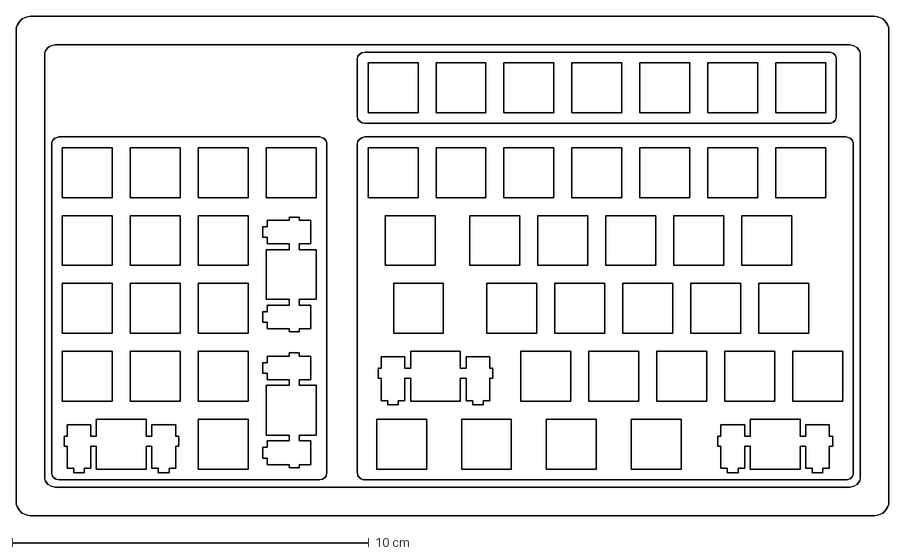
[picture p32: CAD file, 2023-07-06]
housing/keyboardcad/left PCB base.dxf
24.5 x 14.0 cm

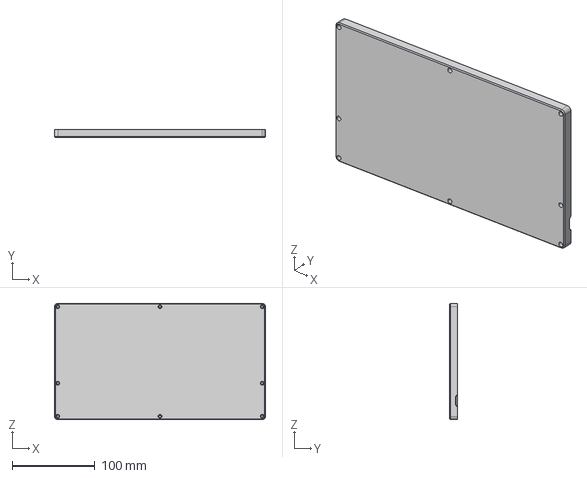
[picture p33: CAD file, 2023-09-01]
housing/result/right bottom plate.step
254.3 x 9.60 x 140.0 mm

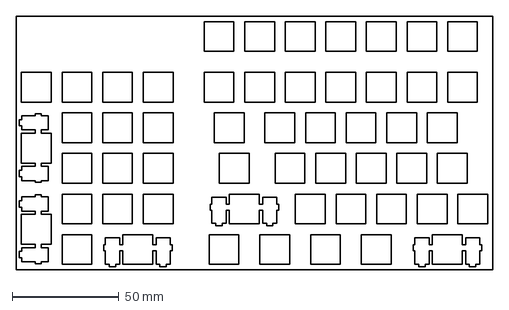
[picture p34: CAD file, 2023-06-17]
housing/keyboardcad/left layout.dxf
223.8 x 119.0 mm

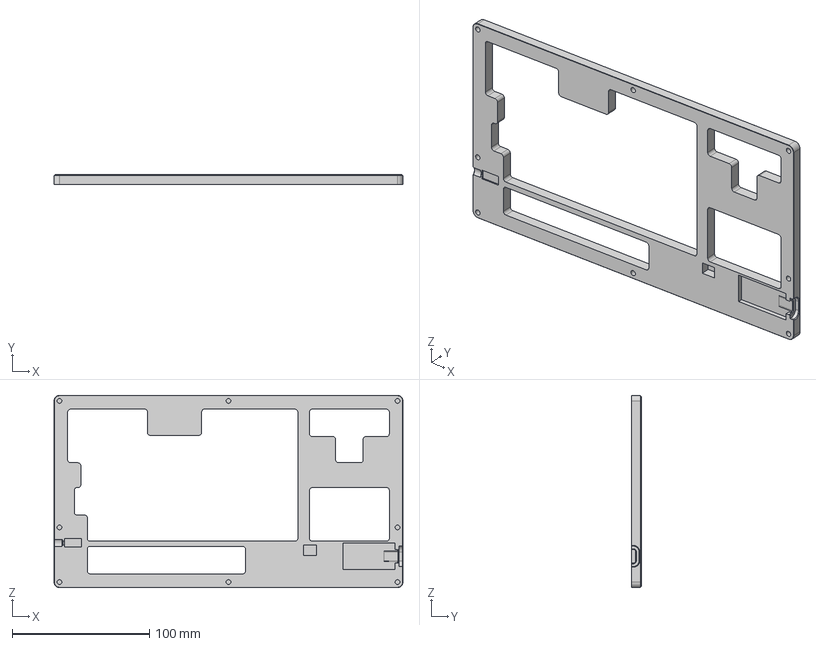
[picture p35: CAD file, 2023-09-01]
housing/result/right top plate.step
254.3 x 7.50 x 140.0 mm

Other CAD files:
housing/result/right plate.step
housing/result/left bottom plate.step
housing/result/right copy - relocated screw holes v2.step
housing/result/left copy - relocated screw holes v2.step

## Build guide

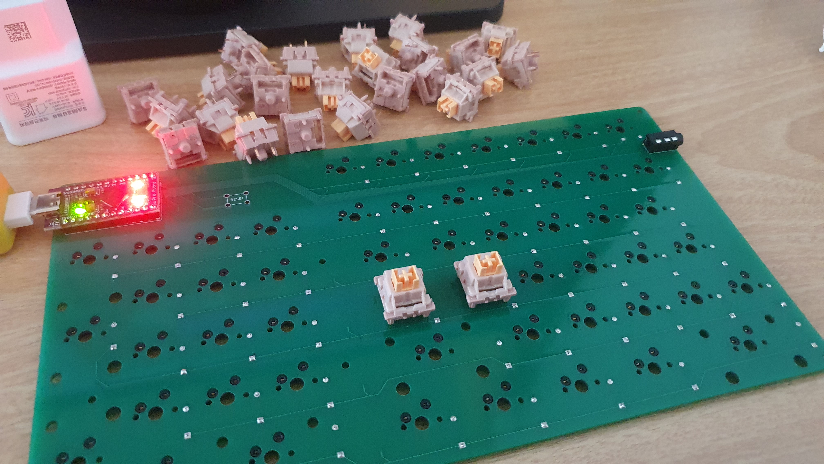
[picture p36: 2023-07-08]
제작기/3. 납땜 & 펌웨어/soldering/leftwork.jpg

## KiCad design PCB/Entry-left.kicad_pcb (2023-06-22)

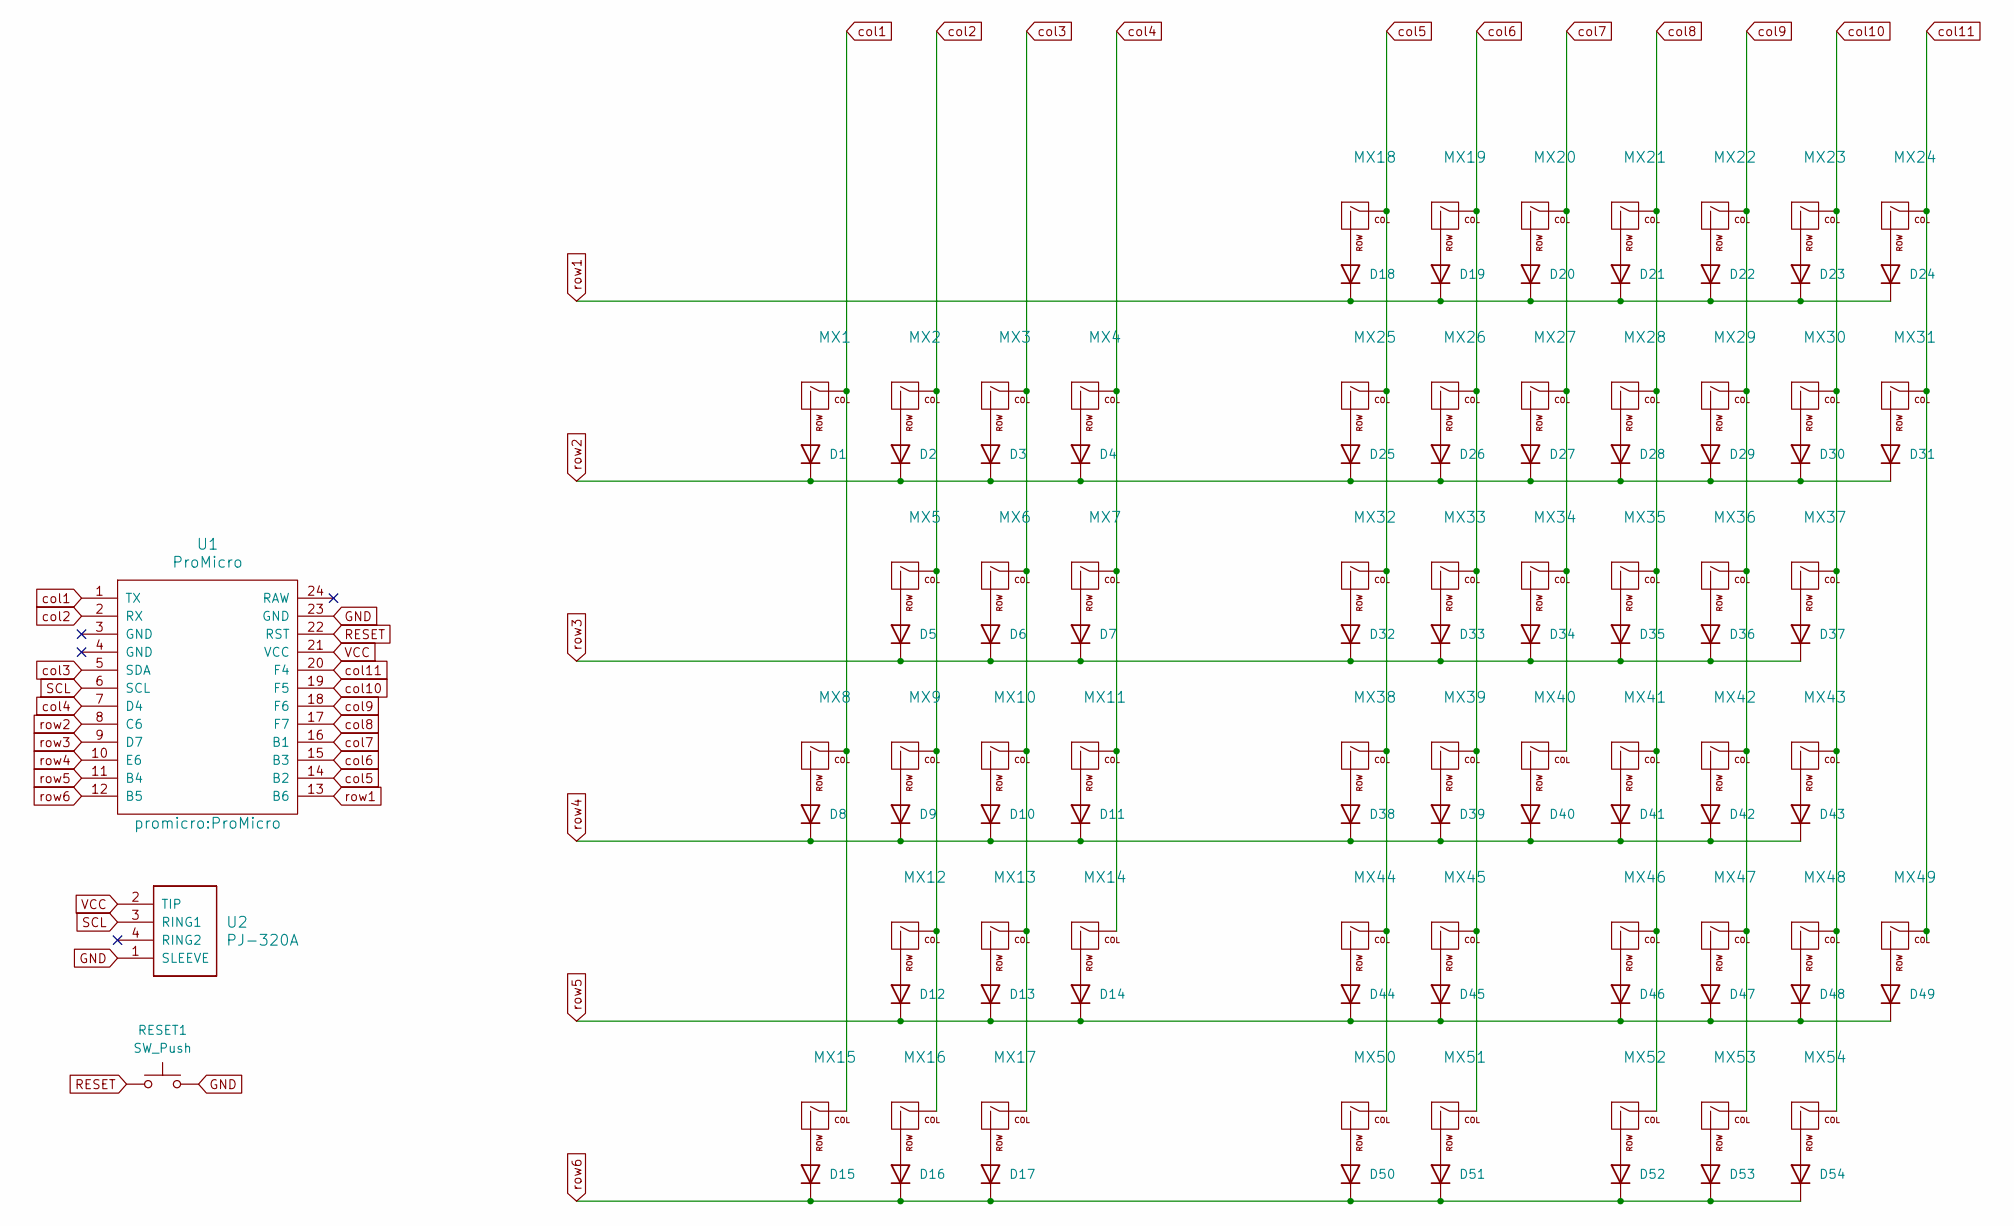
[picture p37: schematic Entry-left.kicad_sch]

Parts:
D1, D2, D3, D4, D5, D6, D7, D8, D9, D10, D11, D12, D13, D14, D15, D16, D17, D18, D19, D20, D21, D22, D23, D24, D25, D26, D27, D28, D29, D30, D31, D32, D33, D34, D35, D36, D37, D38, D39, D40, D41, D42, D43, D44, D45, D46, D47, D48, D49, D50, D51, D52, D53, D54: 1N4148; D_DO-35_SOD27_P7.62mm_Horizontal
MX1, MX2, MX3, MX4, MX5, MX6, MX7, MX9, MX10, MX11, MX12, MX13, MX14, MX16, MX18, MX19, MX20, MX21, MX22, MX23, MX24, MX25, MX26, MX27, MX28, MX29, MX30, MX31, MX33, MX34, MX35, MX36, MX37, MX39, MX40, MX41, MX42, MX43, MX45, MX46, MX47, MX48, MX49: MX-NoLED; MXOnly-1U-Hotswap
MX8, MX15: MX-NoLED; MXOnly-2U-Hotswap-VerticalStabilizers
MX17: MX-NoLED; MXOnly-2U-Hotswap
MX32: MX-NoLED; MXOnly-1.5U-Hotswap
MX38: MX-NoLED; MXOnly-1.75U-Hotswap
MX44, MX54: MX-NoLED; MXOnly-2.25U-Hotswap
MX50, MX51, MX52, MX53: MX-NoLED; MXOnly-1.25U-Hotswap
RESET1: SW_Push; ResetSW_4P
U1: ProMicro
U2: PJ-320A; TRRS-PJ-320A

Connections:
GND: RESET1.2, U1.23 (GND), U2.1 (SLEEVE)
unnamed: D1.2 (A), MX1.2 (ROW)
unnamed: D2.2 (A), MX2.2 (ROW)
unnamed: D3.2 (A), MX3.2 (ROW)
unnamed: D4.2 (A), MX4.2 (ROW)
unnamed: D5.2 (A), MX5.2 (ROW)
unnamed: D6.2 (A), MX6.2 (ROW)
unnamed: D7.2 (A), MX7.2 (ROW)
unnamed: D8.2 (A), MX8.2 (ROW)
unnamed: D9.2 (A), MX9.2 (ROW)
unnamed: D10.2 (A), MX10.2 (ROW)
unnamed: D11.2 (A), MX11.2 (ROW)
unnamed: D12.2 (A), MX12.2 (ROW)
unnamed: D13.2 (A), MX13.2 (ROW)
unnamed: D14.2 (A), MX14.2 (ROW)
unnamed: D15.2 (A), MX15.2 (ROW)
unnamed: D16.2 (A), MX16.2 (ROW)
unnamed: D17.2 (A), MX17.2 (ROW)
unnamed: D18.2 (A), MX18.2 (ROW)
unnamed: D19.2 (A), MX19.2 (ROW)
unnamed: D20.2 (A), MX20.2 (ROW)
unnamed: D21.2 (A), MX21.2 (ROW)
unnamed: D22.2 (A), MX22.2 (ROW)
unnamed: D23.2 (A), MX23.2 (ROW)
unnamed: D24.2 (A), MX24.2 (ROW)
unnamed: D25.2 (A), MX25.2 (ROW)
unnamed: D26.2 (A), MX26.2 (ROW)
unnamed: D27.2 (A), MX27.2 (ROW)
unnamed: D28.2 (A), MX28.2 (ROW)
unnamed: D29.2 (A), MX29.2 (ROW)
unnamed: D30.2 (A), MX30.2 (ROW)
unnamed: D31.2 (A), MX31.2 (ROW)
unnamed: D32.2 (A), MX32.2 (ROW)
unnamed: D33.2 (A), MX33.2 (ROW)
unnamed: D34.2 (A), MX34.2 (ROW)
unnamed: D35.2 (A), MX35.2 (ROW)
unnamed: D36.2 (A), MX36.2 (ROW)
unnamed: D37.2 (A), MX37.2 (ROW)
unnamed: D38.2 (A), MX38.2 (ROW)
unnamed: D39.2 (A), MX39.2 (ROW)
unnamed: D40.2 (A), MX40.2 (ROW)
unnamed: D41.2 (A), MX41.2 (ROW)
unnamed: D42.2 (A), MX42.2 (ROW)
unnamed: D43.2 (A), MX43.2 (ROW)
unnamed: D44.2 (A), MX44.2 (ROW)
unnamed: D45.2 (A), MX45.2 (ROW)
unnamed: D46.2 (A), MX46.2 (ROW)
unnamed: D47.2 (A), MX47.2 (ROW)
unnamed: D48.2 (A), MX48.2 (ROW)
unnamed: D49.2 (A), MX49.2 (ROW)
unnamed: D50.2 (A), MX50.2 (ROW)
unnamed: D51.2 (A), MX51.2 (ROW)
unnamed: D52.2 (A), MX52.2 (ROW)
unnamed: D53.2 (A), MX53.2 (ROW)
unnamed: D54.2 (A), MX54.2 (ROW)
RESET: RESET1.1, U1.22 (RST)
SCL: U1.6 (SCL), U2.3 (RING1)
VCC: U1.21 (VCC), U2.2 (TIP)
col1: MX1.1 (COL), MX8.1 (COL), MX15.1 (COL), U1.1 (TX)
col2: MX2.1 (COL), MX5.1 (COL), MX9.1 (COL), MX12.1 (COL), MX16.1 (COL), U1.2 (RX)
col3: MX3.1 (COL), MX6.1 (COL), MX10.1 (COL), MX13.1 (COL), MX17.1 (COL), U1.5 (SDA)
col4: MX4.1 (COL), MX7.1 (COL), MX11.1 (COL), MX14.1 (COL), U1.7 (D4)
col5: MX18.1 (COL), MX25.1 (COL), MX32.1 (COL), MX38.1 (COL), MX44.1 (COL), MX50.1 (COL), U1.14 (B2)
col6: MX19.1 (COL), MX26.1 (COL), MX33.1 (COL), MX39.1 (COL), MX45.1 (COL), MX51.1 (COL), U1.15 (B3)
col7: MX20.1 (COL), MX27.1 (COL), MX34.1 (COL), MX40.1 (COL), U1.16 (B1)
col8: MX21.1 (COL), MX28.1 (COL), MX35.1 (COL), MX41.1 (COL), MX46.1 (COL), MX52.1 (COL), U1.17 (F7)
col9: MX22.1 (COL), MX29.1 (COL), MX36.1 (COL), MX42.1 (COL), MX47.1 (COL), MX53.1 (COL), U1.18 (F6)
col10: MX23.1 (COL), MX30.1 (COL), MX37.1 (COL), MX43.1 (COL), MX48.1 (COL), MX54.1 (COL), U1.19 (F5)
col11: MX24.1 (COL), MX31.1 (COL), MX49.1 (COL), U1.20 (F4)
row1: D18.1 (K), D19.1 (K), D20.1 (K), D21.1 (K), D22.1 (K), D23.1 (K), D24.1 (K), U1.13 (B6)
row2: D1.1 (K), D2.1 (K), D3.1 (K), D4.1 (K), D25.1 (K), D26.1 (K), D27.1 (K), D28.1 (K), D29.1 (K), D30.1 (K), D31.1 (K), U1.8 (C6)
row3: D5.1 (K), D6.1 (K), D7.1 (K), D32.1 (K), D33.1 (K), D34.1 (K), D35.1 (K), D36.1 (K), D37.1 (K), U1.9 (D7)
row4: D8.1 (K), D9.1 (K), D10.1 (K), D11.1 (K), D38.1 (K), D39.1 (K), D40.1 (K), D41.1 (K), D42.1 (K), D43.1 (K), U1.10 (E6)
row5: D12.1 (K), D13.1 (K), D14.1 (K), D44.1 (K), D45.1 (K), D46.1 (K), D47.1 (K), D48.1 (K), D49.1 (K), U1.11 (B4)
row6: D15.1 (K), D16.1 (K), D17.1 (K), D50.1 (K), D51.1 (K), D52.1 (K), D53.1 (K), D54.1 (K), U1.12 (B5)

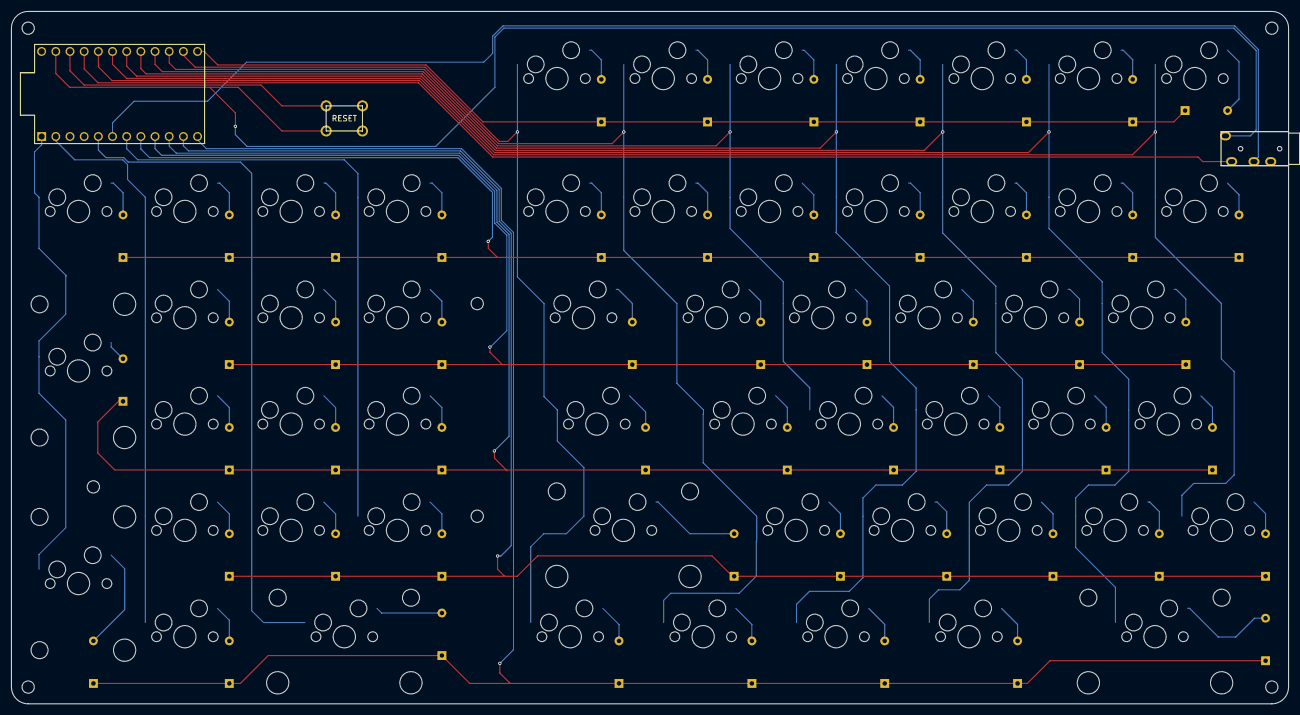
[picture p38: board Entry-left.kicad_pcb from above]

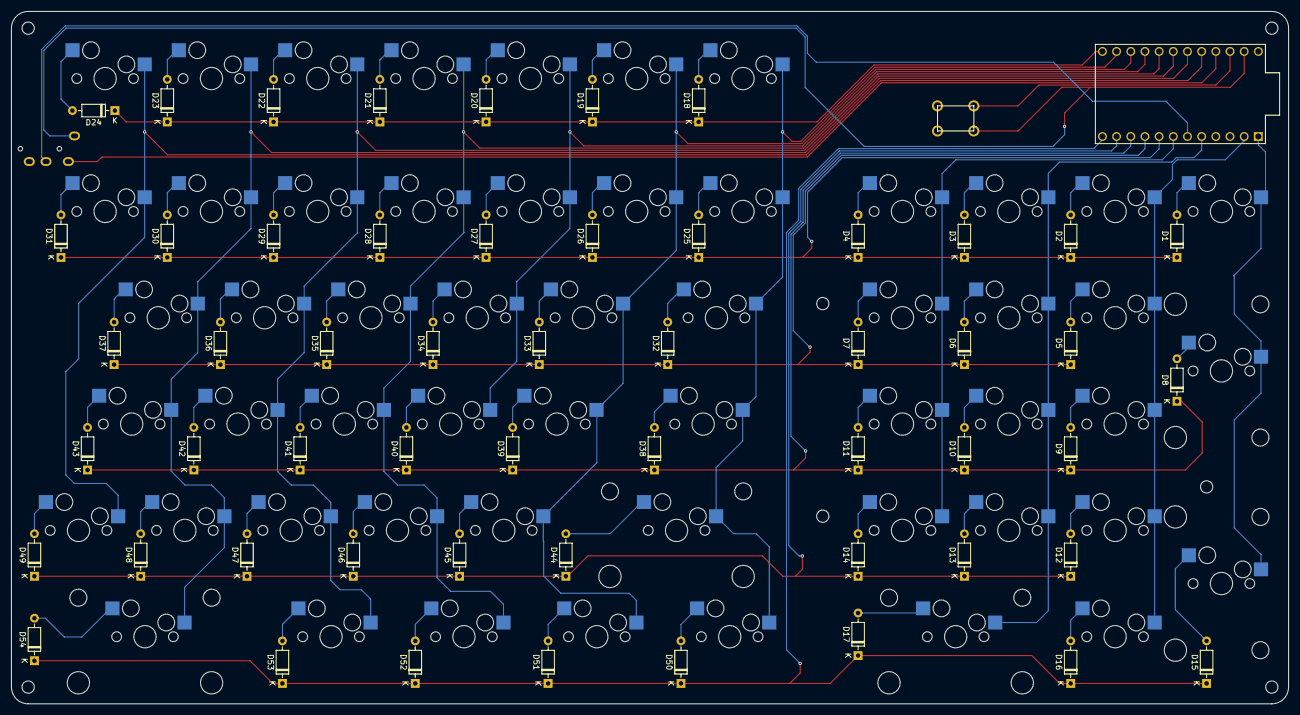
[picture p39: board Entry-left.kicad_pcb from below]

Board: 2 copper layers, 228.8 x 124.1 mm, 111 parts (54 on the bottom side), 75 nets.

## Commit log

2023-06-14 Add: left keyboard pcb and circuit
    [bottom-up-left-ver2.kicad_pcb, bottom-up-left-ver2.kicad_sch, bottom-up-left-ver3.kicad_pcb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]
2023-06-14 docs: 제작기 텍스트 파일 readme로 변경
2023-06-17 Add: reversed numberpad
    [bottom-up-left-ver4.kicad_pcb, bottom-up-left-ver4.kicad_sch]
2023-06-17 Add: plate by generator
    [keyboardcad.dxf, keyboardcad.stl, swillkb-bottom.dxf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]
2023-06-19 Fix: relocated left PCB wire more tight
    [bottom-up-left-ver4.kicad_pcb, bottom-up-left-ver4.kicad_sch]
2023-06-19 Add: right PCB
    [bottom-up-right-base.kicad_pcb, bottom-up-right-base.kicad_sch, bottom-up-right.kicad_pcb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]
2023-06-22 Fix: draw both PCB outline & rename 1. rename project name from 'bottom-up' to 'Entry' 2. removed unused backup files 3. fix both PCB outline - margin 2.5mm, round 3mm 4. made gerber files
    [Entry-left-B_Cu.gbr, Entry-left-B_Mask.gbr, Entry-left-B_Paste.gbr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]
2023-06-23 docs: Edit manufacturing process 2 - edit bolt font on highlights & fix typos
2023-07-04 docs: Edit manufacturing process 3 - housing informantions
2023-07-06 Add: CAD library & specifications
    [keyboardcad.dxf, keyboardcad.stl, left PCB base.dxf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]
2023-07-08 Docs: rename 3.하우징 to 4.하우징
2023-07-08 Rename: rename Entry to PCB
    [Entry-left-B_Cu.gbr, Entry-left-B_Mask.gbr, Entry-left-B_Paste.gbr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]
2023-07-08 Docs: write manufacturing report 3. 납땜 & 펌웨어 제작기
2023-07-08 Rename: rename from plate to housing
    [keyboardcad.dxf, left PCB base.dxf, left PCB v1.dxf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]
2023-07-08 Remove: remove unused files
    [Entry-left-B_Cu.gbr, Entry-left-B_Mask.gbr, Entry-left-B_Paste.gbr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]
2023-08-16 Sync: Append housing database files
    [Entry-left.step, Entry-right.step, left layout.dxf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]
2023-09-01 add: Append housing result step files
    [left bottom plate.step, left copy - relocated screw holes v2.step, left plate.step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]
2024-08-29 fix: Switch option and command key on MACOS
